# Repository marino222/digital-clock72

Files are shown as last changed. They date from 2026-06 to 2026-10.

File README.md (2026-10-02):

# Digital Kinetic Art Clock 

This project is the digital successor to my [ClockClock24 Project](https://github.com/marino222/clockclock24-replica), a replica of the kinetic art piece by [Humans Since 1982](https://www.humanssince1982.com/en-int). The original features physical clock hands driven by stepper motors, which brings challenges around power supply and makes scaling difficult.

This version replaces the clock hands with round LCD displays, which opens up new possibilities beyond just showing the time: animations, a snake game across all displays, or custom widgets. Since the digital version draws significantly less current and is expected to cost less overall, the target scale is a 12×6 display array rather than the 8×3 clocks of the predecessor.

> **Status:** A work in progress

---

## Table of contents

- [Vision](#vision)
- [Key decisions](#key-decisions)
- [How it works](#how-it-works)
- [Repository layout & component status](#repository-layout--component-status)
- [Roadmap](#roadmap)
- [Open questions](#open-questions)

---

## 🌅 Vision

My goal is to build a wall mounted array of round LCD displays that act together as one big synchronized screen. Each display sits in its own spot in a grid, similar to the clocks in the predecessor, but instead of physical hands every spot now has its own small screen.

At first, the array will simply show the time. But since every spot is now a real screen and not just a pair of clock hands, I plan to add more features over time. This includes smooth animations where the hands ease in and out instead of jumping, geometric patterns that move across the whole grid, a snake game that can be played across all displays at once, and small widgets like weather or notifications.

One central computer (likely a Raspberry Pi) will control the whole array and decide what should be shown. It sends this information to every display, and each display takes care of showing its own part of the picture.

---

## 🧩 Concept 

| Aspect | Choice | Why |
|---|---|---|
| Architecture | Master for calulation / Slave for rendering | Real time pixel drawing and global logic need different hardware |
| Master | Raspberry Pi 3, headless Linux broadcasts state at 60 Hz | Global logic and the web UI run better on a Pi than on a microcontroller |
| Node (Slave) | 1× bare RP2040 + 1× GC9A01 round LCD, on a small custom PCB | One identical board, JLCPCB assembled, just replicated |
| Bus | RS485, daisy chained node to node | Carries tiny state packets instead of full frames, so it scales cleanly |
| Applications | Time, animated patterns, array wide games (Snake) | All just different states broadcast by the master |

---

## ⚙️ How it works

To make the vision above work, the project splits the thinking and the drawing onto different controllers. One controller calculates the global image/animation and broadcasts these to the nodes. Each node controller then renders its individual pixels and displays them.

```
        ┌───────────────────────────────────────────────┐
        │  MASTER (Raspberry Pi 3)                      │
        │  • Headless Linux, C#                         │
        │  • Time sync, global vector math, game logic  │
        │  • Web UI for control/config                  │ 
        └───────────────────────┬───────────────────────┘
                                │  RS485 bus (broadcast)
                                │  tiny state packets @ 60 FPS
        ┌───────────┬───────────┼───────────┬───────────┐
        ▼           ▼           ▼           ▼           ▼
     ┌──────┐    ┌──────┐    ┌──────┐    ┌──────┐    ┌──────┐
     │ NODE │    │ NODE │    │ NODE │    │ NODE │    │ NODE │  
     │RP2040│    │  +   │    │  +   │    │  +   │    │  +   │
     │GC9A01│    │ LCD  │    │ LCD  │    │ LCD  │    │ LCD  │
     └──────┘    └──────┘    └──────┘    └──────┘    └──────┘
   Each node renders its own pixels locally from the shared global state.
```

### The master and the slave nodes

One computer, the master controller, runs the whole logic. It keeps track of time, decides what the array should be displaying, and runs a simple web page so it can be controlled. Every screen has its own slave controller, together they make up a node. Each node holds the picture for its own screen and draws it fast enough to keep up with all the others. It also knows its own position in the grid, so it only draws its own little piece of the bigger picture. The work is split this way because one controller can think for the whole array, but it cannot draw fast enough on dozens of screens by itself. And a tiny slave controller is fast enough to draw one screen, but it is too small to run all the planning logic. Splitting the work lets both sides do what they are good at. There is also a hard numeric reason the nodes have to render locally. One screen is 240×240 pixels at 16-bit color (RGB565), so one full frame is 240 × 240 × 2 bytes ≈ **112.5 KiB**. The RP2040 on each node has 264 KiB of SRAM, so it comfortably fits a double buffer for its *own* screen (≈225 KiB) with room to spare.

Read more about the master controller in [`master/README.md`](master/README.md), about the nodes in [`slave/README.md`](slave/README.md), and about the
hardware behind them in [`pcb/README.md`](pcb/README.md).

### How the data is sent to the nodes

Here is the idea that makes the whole array possible. The master does not send a full picture to every screen, sixty times a second. That would be far too much data. Instead, it sends a tiny instruction, something like "the hand should now point at 45 degrees" or "the snake is now at position 12, 2." Every node controller receives the exact same tiny instruction at the exact same moment, and draws its own piece of the picture from it. Streaming one full frame to one screen at 60 FPS is 112.5 KiB × 60 ≈ **6.6 MB/s**, for a single screen alone. For 9 nodes that is already ≈ 60 MB/s, at the full 72-node array it is ≈ 475 MB/s. A wired RS485 bus, the kind of connection this project uses, realistically carries somewhere in the low single-digit Mbit/s over a long daisy chain, several hundred times too little. A state instruction, on the other hand, is a handful of bytes sent once, at 60 Hz, no matter how many screens are listening. That gap is the entire reason the master only ever sends instructions, never pixels. This has three nice side effects. It needs very little data, since an instruction is just a handful of bytes instead of a full image. It keeps everything in sync automatically, since every screen hears the same instruction at the same time. And it scales easily, since adding more screens does not change how much data the brain has to send.

To reliably send state instruction a Data Protocol needs to be defined. Read more about this in [`master/README.md`](master/README.md) and [`slave/README.md`](slave/README.md).

### What actually will be displayed

This instruction can describe anything, which is what makes the project exciting. So far the plan includes:

- **Time:** the original purpose, digits and clock faces drawn across the grid.
- **Geometric and animated patterns:** motion across the whole grid, with easing animations instead of sudden jumps.
- **A snake game:** one game played across the entire array at once.
- **Small widgets:** controlled from the brain's simple web page.
- **Gifs**

---

## 📦 Repository layout & component status

```
Digital Clock 72/
├── 3D files/
│   ├── final/
│   └── test/
├── docs/
│   ├── datasheets/
│   └── images/
├── master/
│   └── README.md
├── slave/
│   └── README.md
├── pcb/
│   ├── node-pcb/
│   └── README.md
├── tests/
│   ├── phase-1.1-display-performance/
│   └── README.md
└── README.md
```

| Path | Tech | Role | Status |
|---|---|---|---|
| **master/** | C# on Pi 3 | Global logic, time sync, vector math, games, web UI, RS485 broadcast | Conceptual |
| **slave/** | C++ (PlatformIO), RP2040 | Framebuffer + SPI/DMA rendering, RS485 receive, local draw, auto-addressing | Conceptual |
| **node_pcb/** | KiCad | Single-node board (RP2040 + GC9A01 display header + RS485 + power + USB-C/SWD) | In design |
| **tests/** | — | Bring-up plan test procedures and recorded results, one folder per phase | Not started |

---

## 🗺️ Roadmap

This roadmap tracks the project progress. The approach is to test cheap, risky parts first before committing to PCB production. The prototype is a **3×3 (9-node)** array, large enough to validate the bus, addressing, and power distribution without high cost. Notes for each phase are listed in [`tests/`](tests/).

| Phase | Goal | Status |
|---|---|---|
| 1 | Test a single display at 60 FPS and measure power | ✅ Completed|
| 2 | Prove the RS485 link with a disposable test sender | ✅ Completed |
| 3 | Prove the state protocol and slave firmware on breadboards | ✅ Completed|
| 4 | Confirm the display hardware | ⚙ In progress |
| 5 | Build small prototype | ⚙ Not started |
| 6 | Scale to 24, then 72 nodes | ⬜ Not started |
| 7 | Add applications and the web UI | ⬜ Not started |

<details>
<summary><strong>1. Test a single display at 60 FPS and measure power</strong></summary>

**1.1 Display performance (breadboard)**
- One GC9A01 dev board driven by a Pico
- Aim for 60 FPS

**1.2 Power measurement (run during 1a)**
- Measure how much power a single display and Pico consume

</details>

<details>
<summary><strong>2. Prove the RS485 link with a disposable test sender</strong></summary>

A slave can't be tested without something transmitting packets, so a sender has to exist this early, but it doesn't need to be the real master. A minimal, throwaway sender (a second Pico, or even a PC-side script) is enough to put bytes on the bus.

**2.1 RS485 link (breadboard)**
- Two Picos + two cheap RS485 breakout modules (MAX3485 / THVD1450).
- One Pico runs a minimal, disposable packet sender the other renders them as a slave.
- The packet should contain very basic instructions so the slave can draw something

</details>

<details>
<summary><strong>3. Prove the state protocol and slave firmware on breadboards</strong></summary>

Develop and test the state protocol and rendering pipeline on breadboards before committing to custom PCBs. Use a Pico as a sender.

**3.1 Protocol design**
- Define and implement the state protocol: time display, basic drawing instructions, interface to implement widgets later
- Build the slave display-list executor: the firmware loop that parses commands, calls into a graphics library (TFT_eSPI or LovyanGFX) and displays pictures

**3.2 Physical testing**
- Test sync accross multiple nodes on 2–3 Picos: one sender, two slaves rendering the same broadcast
- Addressing here is manual, daisy-chain auto-addressing comes later

</details>

<details>
<summary><strong>4. Confirm the display hardware</strong></summary>

**4.1 Display hardware samples**
- Order a handful of the chosen GC9A01 breakout displays before finalizing any PCB.
- Confirm the breakout's pinout/pin order and its mounting-hole pattern / board outline, so the node board's mating board-to-board header position and any standoffs line up

</details>

<details>
<summary><strong>5. Build small prototype</strong></summary>

Before any further testing we should design the PCB as best as we can. Since the minimum order on JLCPCB is 5 pieces, 4 of them should be used to build a 2x2 prototype.

**5.1 PCB Prototype design**
- Design PCB
- Order a small batch (5 Pcs.) and bring up one board: power rails, USB enumeration, flashing, display, RS485 loopback.
- Test if the board works fine: Try to send data packets via RS485 using the sender from Phase 1b
- Measure the power consumption of this board

**5.2 2x2 prototype**
- Add daisy-chain auto-addressing in firmware, now that multiple nodes make it meaningful.
- Create a first version of the master controller in C#
- Assemble prototype and run tests
- Watch for voltage drops along the chain and try the mid-chain injection point to see how much it helps.

</details>

<details>
<summary><strong>6. Scale to 24, then 72 nodes</strong></summary>

**6.1 Scale**
- With real power numbers and a working board/bus, scale up.
- Power distribution will probably need its own pass at this size (multiple supplies, injection points, trace/connector currents).
- Adjust PCB design if anything arises

</details>

<details>
<summary><strong>7. Add applications and the web UI</strong></summary>

**7.1 Applications & web UI**
- Patterns, Snake, widgets. Once the transport feels solid, this part is mostly open-ended.

</details>

---

## ❓ Open questions

- **Power at scale.** See node_pcb's
- **Broadcast protocol definition.** Exact protocol definition. Needs to be implemented in `master` and `slave`.
- **Addressing scheme (firmware).** Daisy-chain auto-addressing to be *implemented* in firmware.
- **Syncing** How to make sure all displays run in sync

---

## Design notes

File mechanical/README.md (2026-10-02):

# Mechanical Design

The project needs an enclosure, plus parts to hold the node PCBs in place.

## Concept

The sketch below shows the rough concept of the clock's physical layout: a 12x6 grid of displays, aligned vertically. A software change could tilt this alignment instead.

The display's [technical drawing](/docs/datasheets/HZ0128QVPHGWS01N-AA.pdf) gives an outer diameter of ≈36 mm. Spacing the displays 44 mm apart gives a visually pleasing result.

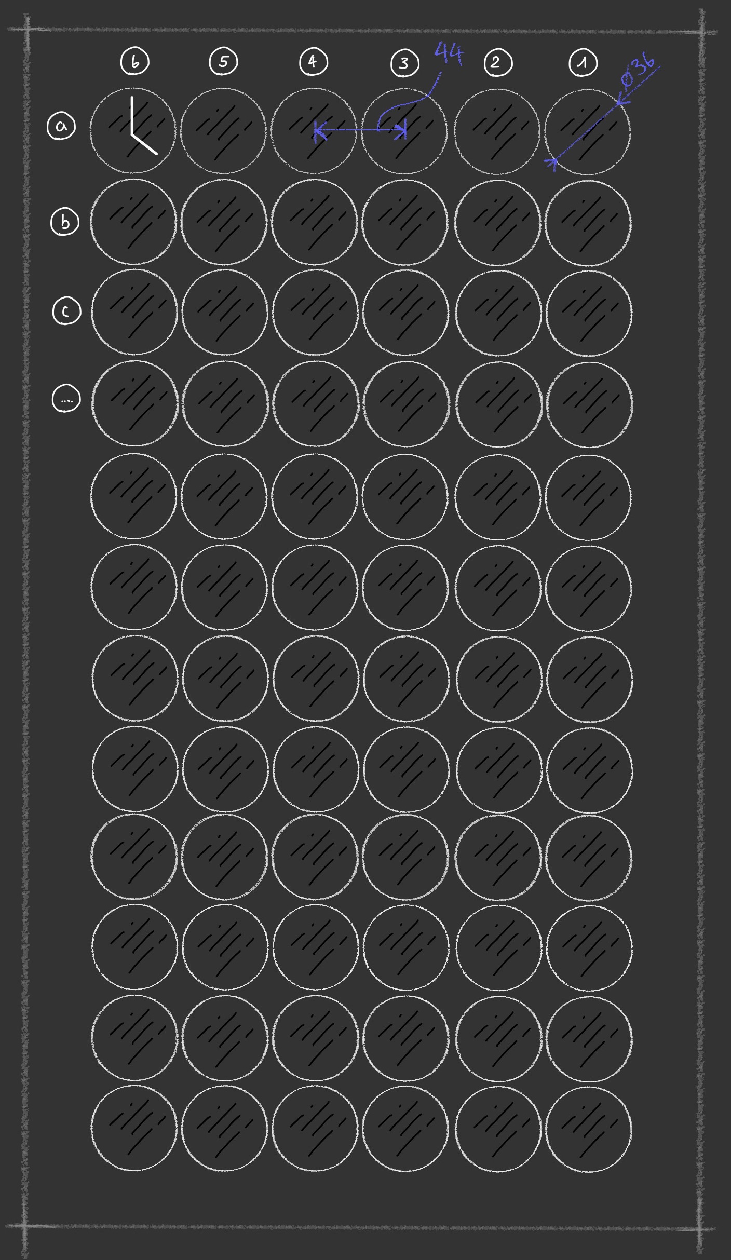
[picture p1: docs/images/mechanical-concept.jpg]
Concept sketch


This spacing means each PCB must fit within 44 x 44 mm, as shown below.

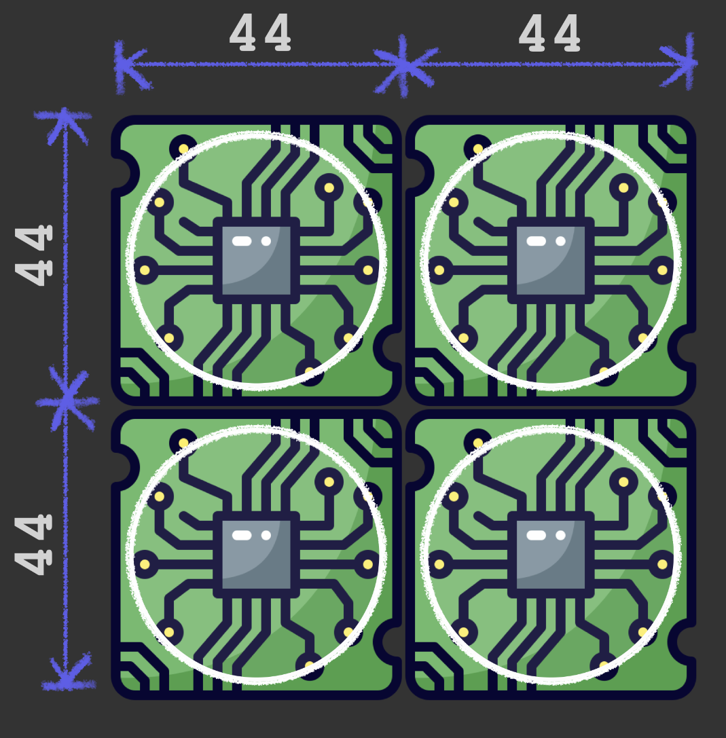
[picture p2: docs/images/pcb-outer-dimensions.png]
PCBs outer dimensions


### PCB outline

The sketch below shows how a node is assembled. The display panel is stuck onto the back of the PCB, and its FPC connector tail wraps around the PCB's edge to reach the connector. A small cutout is needed for the tail so it doesn't interfere with neighboring PCBs. The connector's position will need to match the actual tail length.

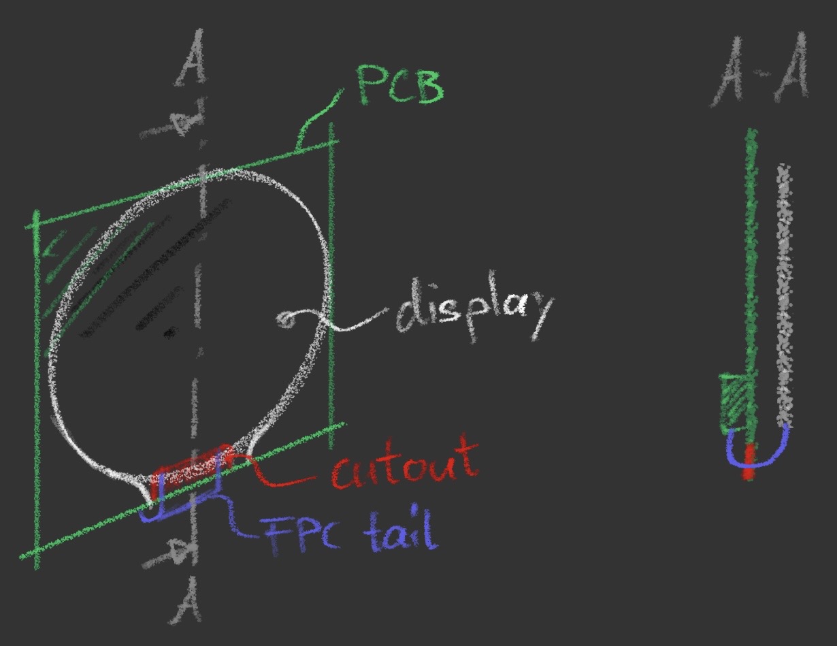
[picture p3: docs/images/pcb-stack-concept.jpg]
PCB stack concept


This gives us the PCB outline shown below, which we need to follow.

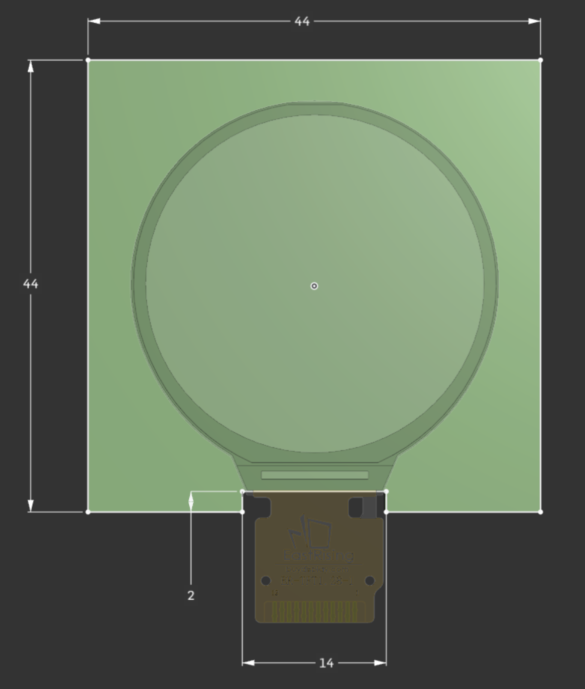
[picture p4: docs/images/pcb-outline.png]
PCB outline


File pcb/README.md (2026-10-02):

# Node PCB

Each pixel node is one self contained board carrying one microcontroller and one round LCD, wired to its neighbors over a shared bus. The full array is this same board built N times, with a target of 72 nodes. This README describes one of the nodes.

## What the board contains

- An RP2040 microcontroller and an external flash chip
- A connector for the GC9A01 round LCD
- An RS485 transceiver and two bus connectors so boards can be daisy chained
- Power regulation, with separate rails for the logic and the display backlight
- USB-C and/or SWD pads for flashing firmware

## Design reference

The board layout follows Raspberry Pi's RP2040 [hardware design guidelines](/docs/datasheets/hardware-design-with-rp2040.pdf), which include a minimal RP2040 example design. Its KiCad files are open source, so they are used as the starting reference.

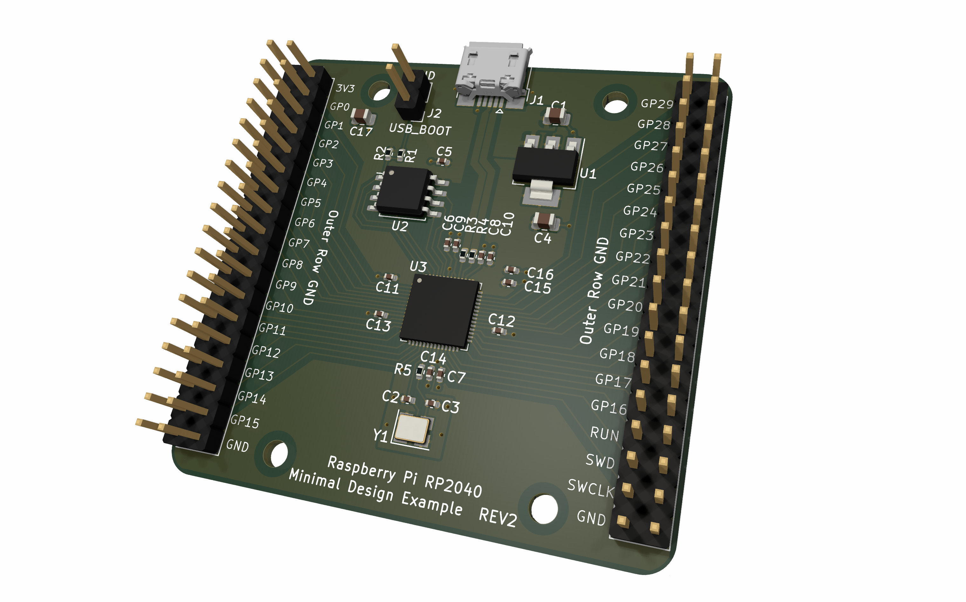
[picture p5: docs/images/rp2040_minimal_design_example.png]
RP2040 minimal design example


The image above shows this minimal design. Core components like the crystal oscillator, flash chip, and voltage regulator should stay the same. From there:

- Remove unnecessary I/O pins
- Add a 12-pin ZIF connector for the display
- Add the components needed for RS485 communication
- Add connectors for the power supply (power is not longer supplied via USB)
- Replace the Bootsel jumper pins (J2) with a button

Only SMD components are used, so the boards can be assembled by machine.

## Block diagram 

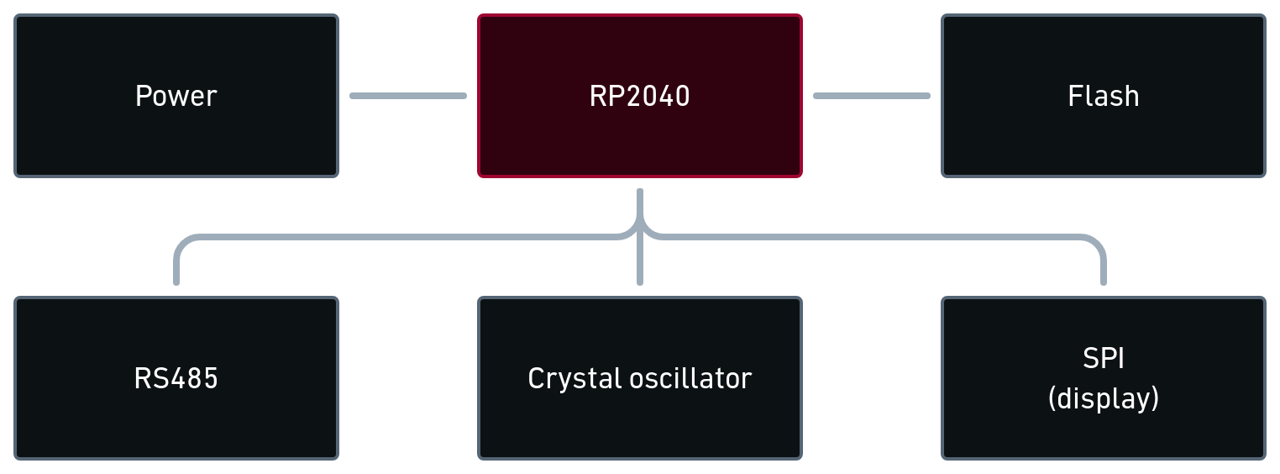
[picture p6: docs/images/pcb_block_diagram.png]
Block diagram of PCB components


## List of components

> All components need to be available in the JLCPCB parts library so they can be used for automatic assembly. Should they not be available, a suitable alternative has to be found.

Common parts like resistors and capacitors are not shown in this list. They may be viewed on the BOM of the final PCB design.

| Part | Manufacturer number | JLCPCB part number |  used in reference design |
| --- | --- | --- | --- |
| MCU | RP2040 | C2040 | ✅ |
| Flash, 4 MB | W25Q32JVS | C97521 | ✅ |
| Crystal, 12 MHz | ABM8-272-T3 | C20625731 | ✅ |
| USB-C connector | TYPE-C-31-M-12 | C165948 | ❌ |
| BOOTSEL button | TS-1187A-B-A-B | C318884 | ❌ |
| RS485 transceiver | THVD1450DR | C2671361  | ❌ |
| ZIF, vertical | AFC11-S12ICA-00 | C262499 | ❌ |
| Schottky diode | B5819W SL | C8598 | ❌ |
| JST connector, 8-pin | BM08B-GHS-TBT(LF)(SN) | C133062 | ❌ |
| LDO voltage regulator | AP2112K-3.3TRG1 | C51118 | ❌ |

> Note that the listed flash chip isn't the same as in the reference design. There a 16 Mb chip is used, which is very likely overkill for this project. To save costs this is scaled down to a 4 Mb chip. For this purpose the [hardware design guidelines](/docs/datasheets/hardware-design-with-rp2040.pdf) explicitly states that most 25-series flash devices may be used. So by using a smaller capacity storage from the same manufacturer shouldn't cause any trouble.

---
---
# Designing the PCB

As a starting point, the KiCad files of the minimal example mentioned above we're copied. 

## Adjusting schematic

The first step is to adjust the [schematic](/docs/datasheets/rp2040-design-example-schematic.pdf) to our needs.

### Power supply

<table>
    <tr>
        <td><b>Before</b></td>
        <td><b>After</b></td>
    <tr>
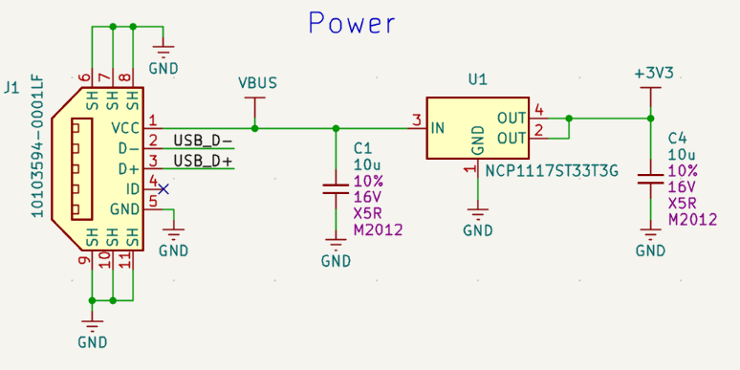
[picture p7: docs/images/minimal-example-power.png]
Minimal design example power block
        <td></td>
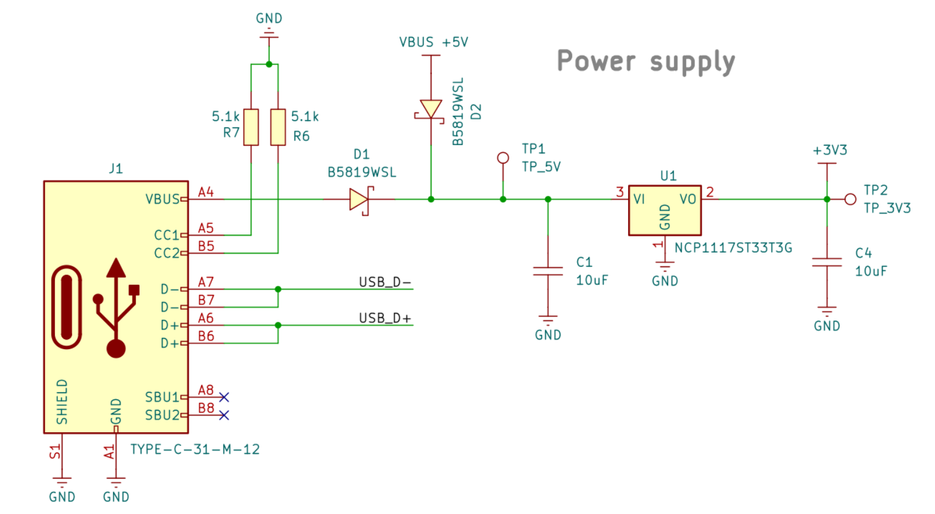
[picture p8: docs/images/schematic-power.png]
schematic power block
        <td></td>
    </tr>
</table>

The image on the left shows the power block of the minimal example, the image on the right shows our version. What changed:

- The Micro USB connector is replaced by a USB-C connector (J1). Its shield pins are tied directly to ground. The two D+ pins (A6/B6) are tied together, and so are the two D- pins (A7/B7), so the port works in either plug orientation. Both pairs then run to the MCU through 33 Ω series resistors.
- CC1 and CC2 are each pulled down with a 5.1 kΩ resistor. This is what tells the host that our board is a sink, so it enables +5 V on VBUS.
- To supply a steady 3.3V, the AP2112K-3.3TRG1 voltage regulater was chosen. This differs from the reference design, mainly because it has a lower dropout voltage (see below)

**Two power sources, two diodes**

During normal operation the board is not powered over USB, that port is only for development and testing. Power comes in over a JST connector, which also carries the RS485 signal lines. Each node has two of these connectors, so a board can be passed through to the next one in a daisy chain.

That means both sources can be present at the same time, so two Schottky diodes keep them apart:

- **D1** sits between the USB-C VBUS pin and the board's internal +5 V node. It lets the USB port feed the board, but blocks current from flowing back into the USB connector.
- **D2** sits between the bus (JST) +5 V net and that same internal node. It lets the bus feed the board, but stops the USB port from feeding the other boards on the bus.

If both sources are active, the board is simply supplied from the one with the higher potential. The price for this protection is a voltage drop across the diode, which is what the rest of this section is about.

#### How much input voltage does one board need?

Figure 1 shows a simplified version of our power supply circuit. The standard case is that the board is supplied from the VBUS line, so the path is JST → D2 → LDO.

<table>
    <tr>
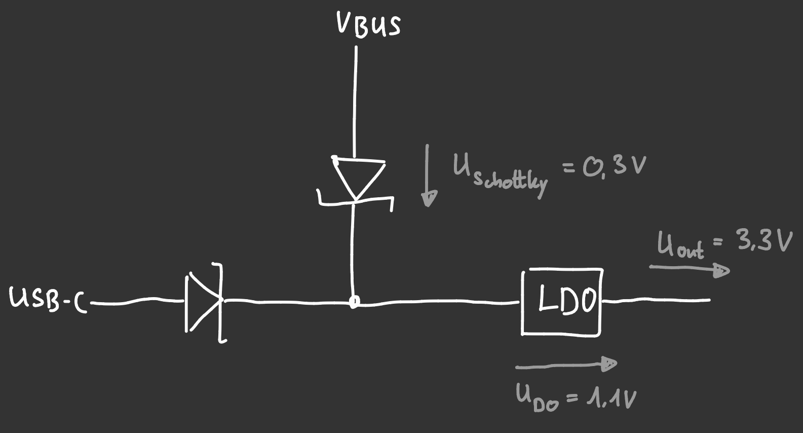
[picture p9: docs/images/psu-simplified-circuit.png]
Simplified power path of one node: VBUS and USB-C each feed the LDO through their own Schottky diode
        <td></td>
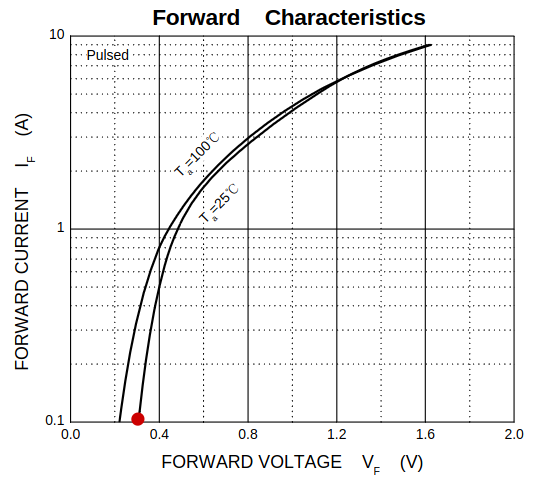
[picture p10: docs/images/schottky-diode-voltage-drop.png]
Forward current over forward voltage of the B5819W Schottky diode
        <td></td>
    </tr>
    <tr>
        <td><b>Figure 1:</b> Simplified power path of one node. Both inputs reach the LDO through their own Schottky diode, so whichever drives the input, one diode drop is always in the way.</td>
        <td><b>Figure 2:</b> Forward characteristics of the B5819W. At I_F = 100 mA (red dot) the forward voltage is roughly 0.3 V.</td>
    </tr>
</table>

In our [tests](/tests/README.md), a single Raspberry Pi Pico plus a display and RS485 module drew around 60 mA. We round this up generously to **100 mA per board**.

Two parts in that path define the minimum input voltage, both taken at 100 mA:

| Part | Value at 100 mA | Source |
| --- | --- | --- |
| Schottky diode (B5819W) | V_F ≈ 0.3 V | [datasheet](/docs/datasheets/schottky-diode-B5817W-589W.pdf), see Figure 2 |
| AP2112K LDO | V_in - V_out ≈ 45 mV | [datasheet](/docs/datasheets/AP2112-LDO.pdf), see Performance Characteristics |

The 45 mV is the LDO's *dropout voltage*: the **minimum** difference the regulator needs between its input and its output. If V_in - V_out falls below it, the LDO drops out of regulation and the 3.3 V rail starts to sag. With V_out = 3.3 V that gives:

```
V_in(LDO) >= V_out + V_dropout = 3.3 V + 0.045 V = 3.345 V
V_bus     >= V_in(LDO) + V_F   = 3.345 V + 0.3 V = 3.645 V
```

So the +5 V on the bus connector must never drop below **≈3.7 V**, anywhere in the installation.

#### How much is left at the last board?

Since we're not living in an ideal world, the supply voltage won't be exactly 5.0 V. We assume the boards are arranged in 12 rows of 6, with a power injection point at the start of each row, as shown in the diagram below. Each row then draws around 6 × 100 mA = 600 mA, which the JST connectors handle comfortably (the GH series is rated for 1.0 A). Most power supply manufacturers specify a voltage tolerance of ±5 %, so in the worst case the PSU delivers 4.75 V instead of 5.00 V.

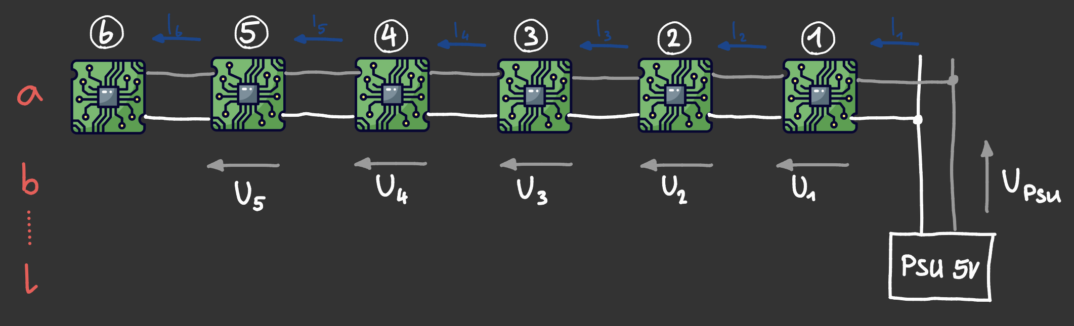
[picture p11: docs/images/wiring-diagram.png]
Wiring diagram


The worst case is node a6: it is the last board of a row and therefore the furthest away from the PSU. Between it and the injection point sit 5 boards and the wires between them, and each of them adds resistance (contacts, pcb traces, wires).

**Estimated resistance per board**

The [datasheet](/docs/datasheets/BM08B-GHS-TBT(LF)(SN).pdf) specifies a contact resistance of 30 mΩ.

Together with the PCB traces and the wire to the next board, we estimate roughly **100 mΩ per hop** for the whole current loop (supply and ground return). The table below shows the resulting voltage drops, with U_n and I_n as labelled in the diagram above:

| Hop | Current | Voltage drop (U = R × I) |
| --- | --- | --- |
| U1 | I1 = 600 mA | 60 mV |
| U2 | I2 = 500 mA | 50 mV |
| U3 | I3 = 400 mA | 40 mV |
| U4 | I4 = 300 mA | 30 mV |
| U5 | I5 = 200 mA | 20 mV |
| **Total** | | **200 mV** |

```
4.75 V (PSU worst case) - 0.20 V (wiring) = 4.55 V at node a6
```

That is well above the minimum of **3.7 V** we calculated earlier.

### Flash storage

<table>
    <tr>
        <td><b>Before</b></td>
        <td><b>After</b></td>
    </tr>
    <tr>
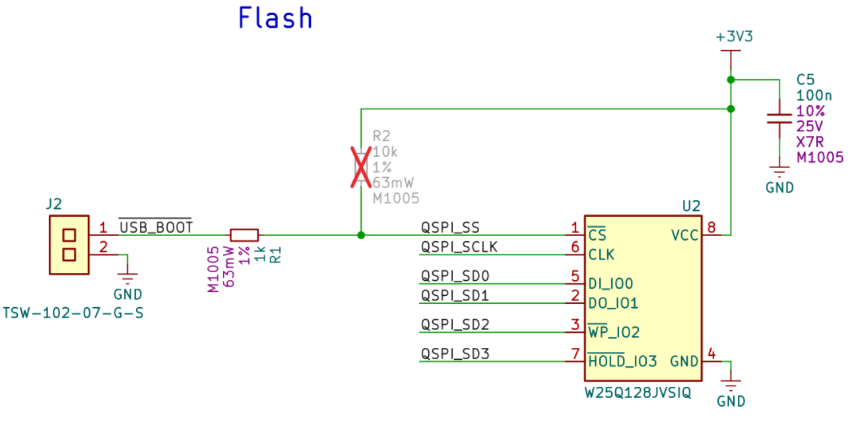
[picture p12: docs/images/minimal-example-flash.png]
Minimal design example flash block
        <td></td>
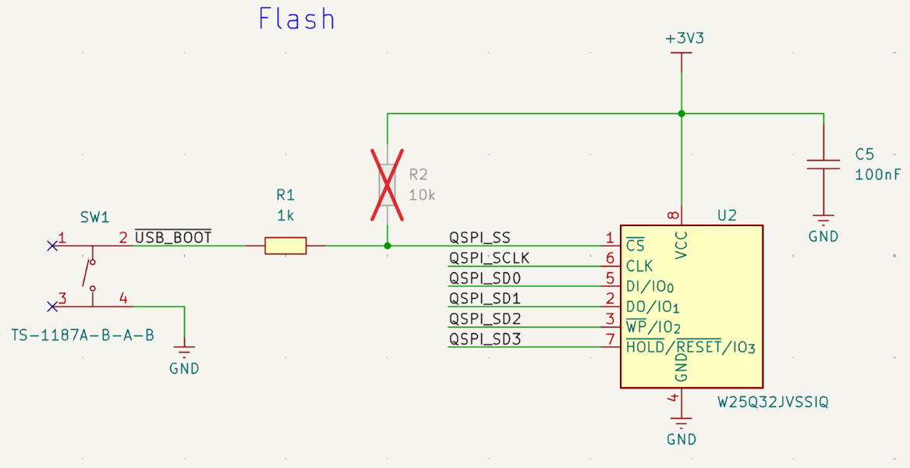
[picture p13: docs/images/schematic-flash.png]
schematic flash block
        <td></td>
    </tr>
</table>

The only changes here are replacing the BOOTSEL jumper J2 with a button (SW1) for easier entry into bootselect mode, and swapping in a different flash chip that shares the exact same footprint as the one in the reference design.

### RS485 communication

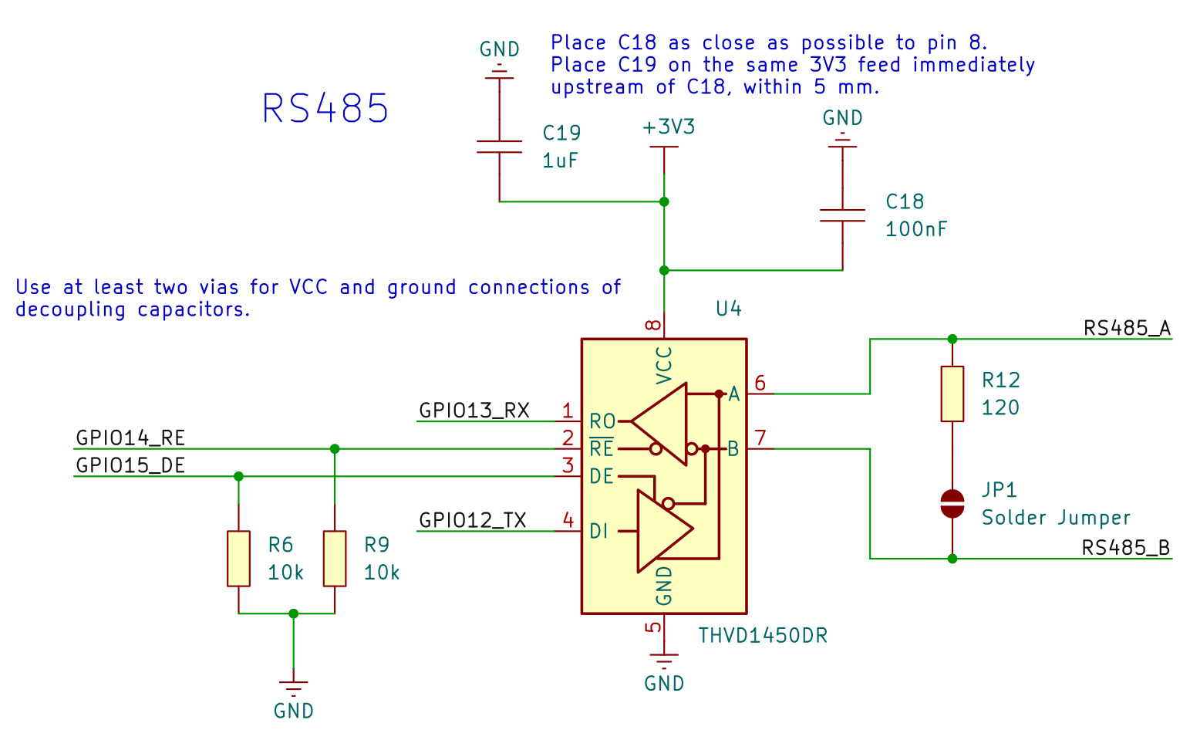
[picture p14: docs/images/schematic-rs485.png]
Schematic RS485


**Why this transceiver.** The THVD1450DR is a 1/8 unit-load part, so up to 256 nodes can share one bus segment. Since the array targets 72 nodes, that leaves plenty of headroom. It is also a common, widely available part and is stocked by JLCPCB.

**What the circuit does.** U4 runs off +3V3 and connects the RP2040's UART to the differential pair:

- `GPIO12_TX` → `DI` and `RO` → `GPIO13_RX` carry the data.
- `GPIO15_DE` and `GPIO14_RE` control the direction. Both are pulled to GND through 10 kΩ (R6, R9), so on power-up the driver is disabled and the receiver is enabled.
- C18 (100 nF) sits directly at pin 8, with C19 (1 µF) immediately upstream on the same 3V3 feed.

This follows the layout guidelines in the chip's [datasheet](/docs/datasheets/thvd1450.pdf), which ask for a 100–220 nF cap as close as possible to VCC, at least two vias per decoupling connection, and 1–10 kΩ resistors on the enable lines to limit noise currents during transients. 

**Termination.** R12 (120 Ω) is populated on every board but sits in series with solder jumper JP1, so it is only in circuit once that jumper is bridged. That matters because of how the array is wired. Looking back at the [wiring diagram](/docs/images/wiring-diagram.png), this is not one continuous bus. The 72 nodes are split into 12 rows of 6, each fed from its own injection point, so electrically there are 12 separate branches. Each branch is a short run, and terminating all 24 ends is likely overkill. How many jumpers actually need bridging still has to be measured on real hardware.

### Daisy chain connector

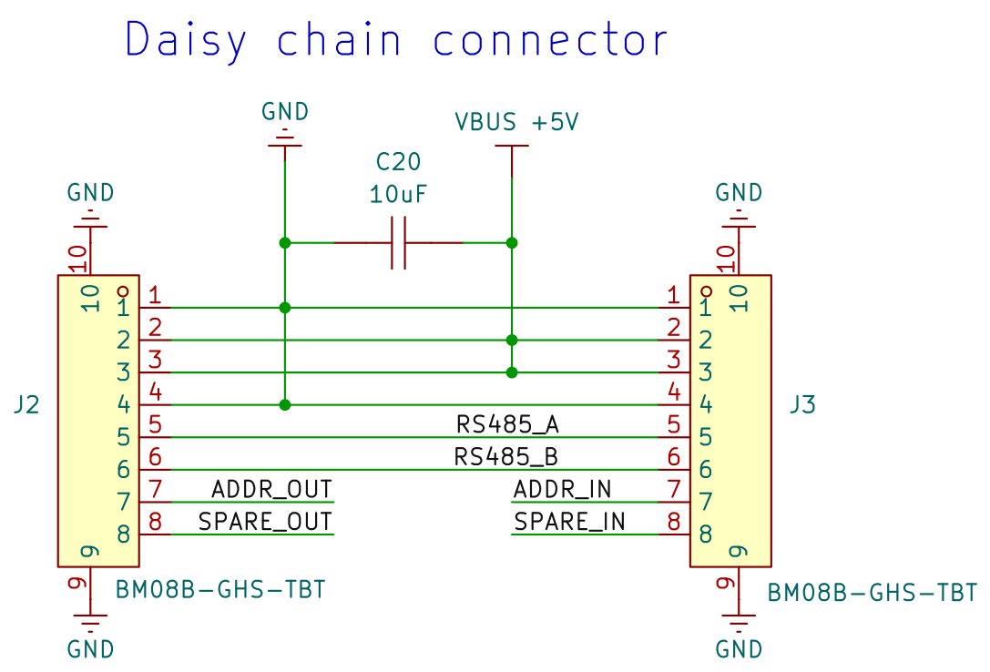
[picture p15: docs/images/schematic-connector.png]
Schematic daisy chain connector


Boards are linked with 8-pin JST GH connectors (BM08B-GHS-TBT), one in (J3) and one out (J2). 

The eight lines are allocated as follows:

| Pins | Net | Notes |
| --- | --- | --- |
| 1, 4 | GND | Split across two pins |
| 2, 3 | +5V (VBUS) | Split across two pins |
| 5, 6 | RS485_A / RS485_B | Passed straight through |
| 7 | ADDR | Point to point, for auto-addressing |
| 8 | SPARE | Point to point, reserved |

Power and ground each get two pins on purpose. The GH series is rated for 1.0 A per contact with AWG #26 wire, so doubling up gives a comfortable 2 A budget.

The last two lines are wired differently from the rest. Power, ground and the RS485 pair passed straight through the board, `ADDR` and `SPARE` are not. `ADDR_IN`/`SPARE_IN` on J3 and `ADDR_OUT`/`SPARE_OUT` on J2 are four separate nets going to four separate GPIOs. `ADDR` is used for the auto adressing feature. `SPARE` is the same arrangement with nothing assigned to it yet, wired up proactively so a future feature can use it without a board change.

C20 (10 µF) provides local bulk decoupling between +5V and GND at the connector.
AP2112K-3.3TRG1

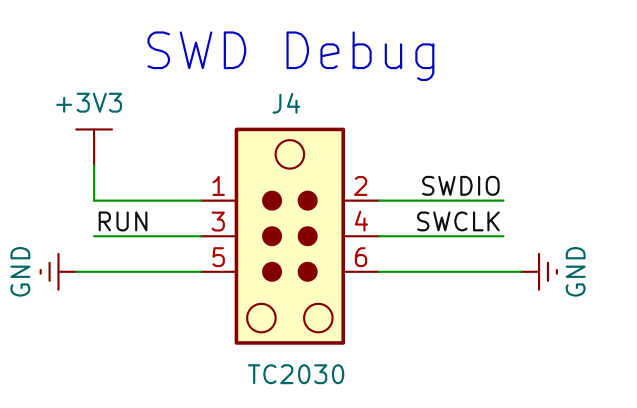
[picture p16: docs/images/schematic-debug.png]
Schematic SWD debug


An SWD header (J4) was added alongside USB-C to make flashing and debugging easier. The footprint is a standard TC2030, which needs no connector on the board at all. A pogo pin cable is simply pressed against the pads.

On the other end, the plan is to drive it from a second Raspberry Pi Pico running the official debugprobe firmware, which handles both flashing and interactive debugging over the same three wires.

### SPI display

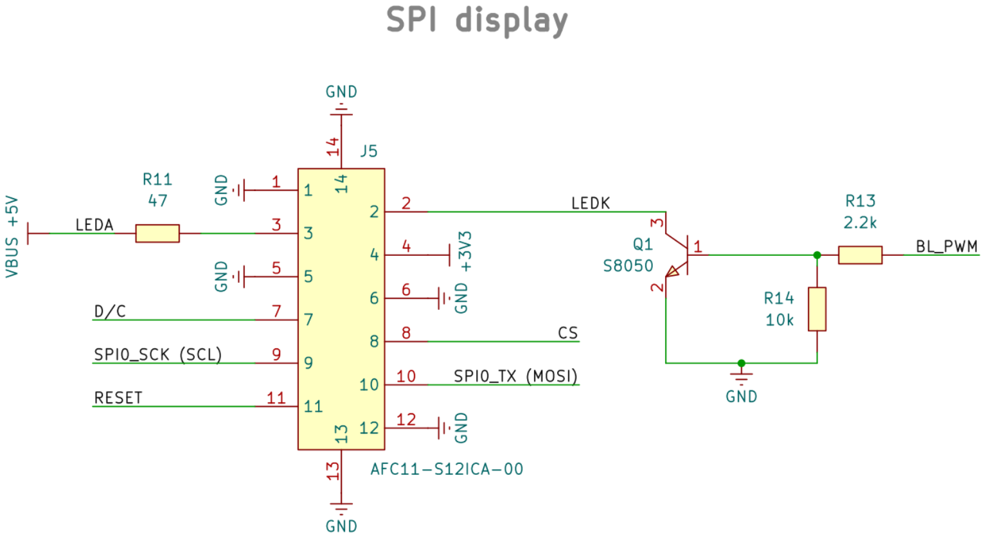
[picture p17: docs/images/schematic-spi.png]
Schematic SPI


The display's FPC tail plugs into J5, a 12-pin ZIF (zero insertion force) connector, so the panel can be swapped without soldering. The assignment follows the tail pinout given in the panel [datasheet](/docs/datasheets/HZ0128QVPHGWS01N-AA).

| Pin | Net | Purpose |
| --- | --- | --- |
| 1 | GND | |
| 2 | LEDK | Backlight cathode, switched by Q1 |
| 3 | LEDA | Backlight anode, +5V through R11 |
| 4 | +3V3 | VDD, analog supply |
| 5, 6 | GND | |
| 7 | D/C | Data / command select |
| 8 | CS | Chip select, active low |
| 9 | SPI0_SCK | Serial clock |
| 10 | SPI0_TX | Serial data in |
| 11 | RESET | Active low |
| 12 | GND | |
| 13, 14 | GND | Mounting tabs |

Ten of the twelve pins are unremarkable: the 4-wire SPI signals, `RESET`, the 3V3 analog supply and four grounds. Note that VDD is specified as 2.8 V typical with an absolute maximum of 4.6 V, so it belongs on the logic rail, the +5V rail is only for the backlight.

**The backlight.** This is the one block that needs more than a wire. The panel carries two white LEDs in parallel, specified at VF ≈ 3.0 V and IF = 40 mA, and it has no driver of its own.

`LEDA` (pin 3) is fed from +5V rather than the 3V3 rail, because 3.3 V leaves almost no headroom above the 3.0 V forward voltage. `LEDK` (pin 2) is then switched low-side by Q1, an S8050 NPN. `BL_PWM` drives the base through R13 (2.2 kΩ), and R14 (10 kΩ) pulls the base down so the backlight stays dark until the firmware deliberately drives the pin. Varying the PWM duty cycle dims the display.

R11 (47 Ω) sits in series with the anode and sets the current:

```
I = (5 V − 3.0 V − 0.2 V) / 47 Ω ≈ 38 mA
```

with the 0.2 V accounting for Q1's collector-emitter saturation voltage. That lands just under the 40 mA rating, which is where we want to be.

## Open uncertainties

- The GC9A01 FPC tail spec (pin count, pitch, orientation) needs to be confirmed from physical samples, and the ZIF pin assignment corrected to match (see the SPI section).
- Real per node power draw (idle, full white, inrush) hasn't been measured yet.
- The THVD1450 is in the schematic, but the slower, lower-EMI THVD1410 may be the better fit for this bus.
- How many of the 12 branches actually need their 120 Ω termination jumper bridged has to be measured.
- Baud rate vs. max bus length for the largest planned install needs to be decided.

See the root [README.md](../README.md) for full system context.

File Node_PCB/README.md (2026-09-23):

# Node PCB

Each pixel node is one self contained board carrying one microcontroller and one round LCD, wired to its neighbors over a shared bus. The full array is this same board built N times, with a target of 72 nodes. This README describes one of the nodes.

## What the board contains

- An RP2040 microcontroller and an external flash chip
- A connector for the GC9A01 round LCD
- An RS485 transceiver and two bus connectors so boards can be daisy chained
- Power regulation, with separate rails for the logic and the display backlight
- USB-C and/or SWD pads for flashing firmware

## Design reference

The board layout follows Raspberry Pi's RP2040 [hardware design guidelines](/docs/datasheets/hardware-design-with-rp2040.pdf), which include a minimal RP2040 example design. Its KiCad files are open source, so they are used as the starting reference.

RP2040 minimal design example

The image above shows this minimal design. Core components like the crystal oscillator, flash chip, and voltage regulator should stay the same. From there:

- Remove unnecessary I/O pins
- Add a 12-pin ZIF connector for the display
- Add the components needed for RS485 communication
- Add connectors for the power supply (power is not longer supplied via USB)
- Replace the Bootsel jumper pins (J2) with a button

Only SMD components are used, so the boards can be assembled by machine.

## Block diagram 

Block diagram of PCB components

## List of components

> All components need to be available in the JLCPCB parts library so they can be used for automatic assembly. Should they not be available, a suitable alternative has to be found.

Common parts like resistors and capacitors are not shown in this list. They may be viewed on the BOM of the final PCB design.

| Part | Manufacturer number | JLCPCB part number |  used in reference design |
| --- | --- | --- | --- |
| MCU | RP2040 | C2040 | ✅ |
| Flash, 4 MB | W25Q32JVS | C97521 | ✅ |
| Crystal, 12 MHz | ABM8-272-T3 | C20625731 | ✅ |
| USB-C connector | TYPE-C-31-M-12 | C165948 | ❌ |
| BOOTSEL button | TS-1187A-B-A-B | C318884 | ❌ |
| RS485 transceiver | THVD1450DR | C2671361  | ❌ |
| ZIF, vertical | AFC11-S12ICA-00 | C262499 | ❌ |
| Schottky diode | B5819W SL | C8598 | ❌ |
| JST connector, 8-pin | BM08B-GHS-TBT(LF)(SN) | C133062 | ❌ |

> Note that the listed flash chip isn't the same as in the reference design. There a 16 Mb chip is used, which is very likely overkill for this project. To save costs this is scaled down to a 4 Mb chip. For this purpose the [hardware design guidelines](/docs/datasheets/hardware-design-with-rp2040.pdf) explicitly states that most 25-series flash devices may be used. So by using a smaller capacity storage from the same manufacturer shouldn't cause any trouble.

---
---
# Designing the PCB

As a starting point, the KiCad files of the minimal example mentioned above we're copied. 

## Adjusting schematic

The first step is to adjust the [schematic](/docs/datasheets/rp2040-design-example-schematic.pdf) to our needs.

### Power supply

<table>
    <tr>
        <td><b>Before</b></td>
        <td><b>After</b></td>
    <tr>
        <td>Minimal design example power block</td>
        <td>schematic power block</td>
    </tr>
</table>

The image on the left shows the power block of the minimal example, the image on the right shows our version. What changed:

- The Micro USB connector is replaced by a USB-C connector (J1). Its shield pins are tied directly to ground. The two D+ pins (A6/B6) are tied together, and so are the two D- pins (A7/B7), so the port works in either plug orientation. Both pairs then run to the MCU through 33 Ω series resistors.
- CC1 and CC2 are each pulled down with a 5.1 kΩ resistor. This is what tells the host that our board is a sink, so it enables +5 V on VBUS.
- The regulator stays as it is in the reference design: U1 (NCP1117) turns the +5 V input into the +3.3 V logic rail.

**Two power sources, two diodes**

During normal operation the board is not powered over USB — that port is only for development and testing. Power comes in over a JST connector, which also carries the RS485 signal lines. Each node has two of these connectors, so a board can be passed through to the next one in a daisy chain.

That means both sources can be present at the same time, so two Schottky diodes keep them apart:

- **D1** sits between the USB-C VBUS pin and the board's internal +5 V node. It lets the USB port feed the board, but blocks current from flowing back into the USB connector.
- **D2** sits between the bus (JST) +5 V net and that same internal node. It lets the bus feed the board, but stops the USB port from feeding the other boards on the bus.

If both sources are active, the board is simply supplied from the one with the higher potential. The price for this protection is a voltage drop across the diode, which is what the rest of this section is about.

#### How much input voltage does one board need?

Figure 1 shows a simplified version of our power supply circuit. The standard case is that the board is supplied from the VBUS line, so the path is JST → D2 → LDO.

<table>
    <tr>
        <td>Simplified power path of one node: VBUS and USB-C each feed the LDO through their own Schottky diode</td>
        <td>Forward current over forward voltage of the B5819W Schottky diode</td>
    </tr>
    <tr>
        <td><b>Figure 1:</b> Simplified power path of one node. Both inputs reach the LDO through their own Schottky diode, so whichever drives the input, one diode drop is always in the way.</td>
        <td><b>Figure 2:</b> Forward characteristics of the B5819W. At I_F = 100 mA (red dot) the forward voltage is roughly 0.3 V.</td>
    </tr>
</table>

In our [tests](/tests/README.md), a single Raspberry Pi Pico plus a display and RS485 module drew around 60 mA. We round this up generously to **100 mA per board**.

Two parts in that path define the minimum input voltage, both taken at 100 mA:

| Part | Value at 100 mA | Source |
| --- | --- | --- |
| Schottky diode (B5819W) | V_F ≈ 0.3 V | [datasheet](/docs/datasheets/schottky-diode-B5817W-589W.pdf), see Figure 2 |
| NCP1117 LDO | V_in - V_out = 1.10 V (max) | [datasheet](/docs/datasheets/NCP1117-LDO.PDF), 0.95 V typical / 1.10 V max |

The 1.10 V is the LDO's *dropout voltage*: the **minimum** difference the regulator needs between its input and its output. If V_in - V_out falls below it, the LDO drops out of regulation and the 3.3 V rail starts to sag. With V_out = 3.3 V that gives:

```
V_in(LDO) >= V_out + V_dropout = 3.3 V + 1.10 V = 4.40 V
V_bus     >= V_in(LDO) + V_F   = 4.40 V + 0.3 V = 4.70 V
```

So the +5 V on the bus connector must never drop below **4.7 V**, anywhere in the installation.

#### How much is left at the last board?

Since we're not living in an ideal world, the supply voltage won't be exactly 5.0 V. We assume the boards are arranged in 12 rows of 6, with a power injection point at the start of each row, as shown in the diagram below. Each row then draws around 6 × 100 mA = 600 mA, which the JST connectors handle comfortably (the GH series is rated for 1.0 A). Most power supply manufacturers specify a voltage tolerance of ±5 %, so in the worst case the PSU delivers 4.75 V instead of 5.00 V.

Wiring diagram

The worst case is node a6: it is the last board of a row and therefore the furthest away from the PSU. Between it and the injection point sit 5 boards and the wires between them, and each of them adds resistance (contacts, pcb traces, wires).

**Estimated resistance per board**

The [datasheet](/docs/datasheets/BM08B-GHS-TBT(LF)(SN).pdf) specifies a contact resistance of 30 mΩ.

Together with the PCB traces and the wire to the next board, we estimate roughly **100 mΩ per hop** for the whole current loop (supply and ground return). The table below shows the resulting voltage drops, with U_n and I_n as labelled in the diagram above:

| Hop | Current | Voltage drop (U = R × I) |
| --- | --- | --- |
| U1 | I1 = 600 mA | 60 mV |
| U2 | I2 = 500 mA | 50 mV |
| U3 | I3 = 400 mA | 40 mV |
| U4 | I4 = 300 mA | 30 mV |
| U5 | I5 = 200 mA | 20 mV |
| **Total** | | **200 mV** |

```
4.75 V (PSU worst case) - 0.20 V (wiring) = 4.55 V at node a6
```

That is 0.15 V short of the 4.7 V we calculated as the minimum input voltage.

In reality this will probably still be fine, because every assumption above is a worst case. The PSU at the bottom of its tolerance, 100 mA per board when we measured 60 mA, and the full current charged to every hop. On the other hand, the 0.3 V diode drop is read off a typical curve and not a guaranteed maximum, so it could also turn out slightly worse.

Either way, the 100 mΩ per hop is an estimate. Once the first batch of PCBs arrives we have to measure the actual resistance and the voltage that really arrives at the last node (see [tests](../tests/README.md#pcb-prototype-design) for the measured results).

### Flash storage

<table>
    <tr>
        <td><b>Before</b></td>
        <td><b>After</b></td>
    </tr>
    <tr>
        <td>Minimal design example flash block</td>
        <td>schematic flash block</td>
    </tr>
</table>

The only changes here are replacing the BOOTSEL jumper J2 with a button (SW1) for easier entry into bootselect mode, and swapping in a different flash chip that shares the exact same footprint as the one in the reference design.

### RS485 communication

Schematic RS485

**Why this transceiver.** The THVD1450DR is a 1/8 unit-load part, so up to 256 nodes can share one bus segment. Since the array targets 72 nodes, that leaves plenty of headroom. It is also a common, widely available part and is stocked by JLCPCB.

**What the circuit does.** U4 runs off +3V3 and connects the RP2040's UART to the differential pair:

- `GPIO12_TX` → `DI` and `RO` → `GPIO13_RX` carry the data.
- `GPIO15_DE` and `GPIO14_RE` control the direction. Both are pulled to GND through 10 kΩ (R6, R9), so on power-up the driver is disabled and the receiver is enabled.
- C18 (100 nF) sits directly at pin 8, with C19 (1 µF) immediately upstream on the same 3V3 feed.

This follows the layout guidelines in the chip's [datasheet](/docs/datasheets/thvd1450.pdf), which ask for a 100–220 nF cap as close as possible to VCC, at least two vias per decoupling connection, and 1–10 kΩ resistors on the enable lines to limit noise currents during transients. 

**Termination.** R12 (120 Ω) is populated on every board but sits in series with solder jumper JP1, so it is only in circuit once that jumper is bridged. That matters because of how the array is wired. Looking back at the [wiring diagram](/docs/images/wiring-diagram.png), this is not one continuous bus. The 72 nodes are split into 12 rows of 6, each fed from its own injection point, so electrically there are 12 separate branches. Each branch is a short run, and terminating all 24 ends is likely overkill. How many jumpers actually need bridging still has to be measured on real hardware.

> **Note on the part number.** The THVD1450 is the 50 Mbps variant of the family, the pin-compatible THVD1410 is the 500 kbps.

### Daisy chain connector

Schematic daisy chain connector

Boards are linked with 8-pin JST GH connectors (BM08B-GHS-TBT), one in (J3) and one out (J2). Two things made this the pick:

- **Top entry.** The gap between adjacent boards is not confirmed yet. A vertical connector routes the cable away from the board edge, so the gap size does not constrain the choice. A side-entry part (SM08B-GHS-TB) would.
- **SMT.** The whole board is machine assembled, and this header is surface mount, so no hand soldering step is needed.

The eight lines are allocated as follows:

| Pins | Net | Notes |
| --- | --- | --- |
| 1, 4 | GND | Split across two pins |
| 2, 3 | +5V (VBUS) | Split across two pins |
| 5, 6 | RS485_A / RS485_B | Passed straight through |
| 7 | ADDR | Point to point, for auto-addressing |
| 8 | SPARE | Point to point, reserved |

Power and ground each get two pins on purpose. The GH series is rated for 1.0 A per contact with AWG #26 wire, so doubling up gives a comfortable 2 A budget.

The last two lines are wired differently from the rest. Power, ground and the RS485 pair passed straight through the board, `ADDR` and `SPARE` are not. `ADDR_IN`/`SPARE_IN` on J3 and `ADDR_OUT`/`SPARE_OUT` on J2 are four separate nets going to four separate GPIOs. `ADDR` is used for the auto adressing feature. `SPARE` is the same arrangement with nothing assigned to it yet, wired up proactively so a future feature can use it without a board change.

C20 (10 µF) provides local bulk decoupling between +5V and GND at the connector.

### SWD debug interface

Schematic SWD debug

An SWD header (J4) was added alongside USB-C to make flashing and debugging easier. The footprint is a standard TC2030, which needs no connector on the board at all. A pogo pin cable is simply pressed against the pads.

On the other end, the plan is to drive it from a second Raspberry Pi Pico running the official debugprobe firmware, which handles both flashing and interactive debugging over the same three wires.

### SPI display

Schematic SPI

The display's FPC tail plugs into J5, a 12-pin ZIF (zero insertion force) connector, so the panel can be swapped without soldering. The assignment follows the tail pinout given in the panel [datasheet](/docs/datasheets/HZ0128QVPHGWS01N-AA.pdf), which the two [GoldenMorning T128HC](/docs/datasheets/display-datasheets/) drawings of the same 12-pin tail agree with:

| Pin | Net | Purpose |
| --- | --- | --- |
| 1 | GND | |
| 2 | LEDK | Backlight cathode, switched by Q1 |
| 3 | LEDA | Backlight anode, +5V through R11 |
| 4 | +3V3 | VDD, analog supply |
| 5, 6 | GND | |
| 7 | D/C | Data / command select |
| 8 | CS | Chip select, active low |
| 9 | SPI0_SCK | Serial clock |
| 10 | SPI0_TX | Serial data in |
| 11 | RESET | Active low |
| 12 | GND | |
| 13, 14 | GND | Mounting tabs |

Ten of the twelve pins are unremarkable: the 4-wire SPI signals, `RESET`, the 3V3 analog supply and four grounds. Note that VDD is specified as 2.8 V typical with an absolute maximum of 4.6 V, so it belongs on the logic rail, the +5V rail is only for the backlight.

**The backlight.** This is the one block that needs more than a wire. The panel carries two white LEDs in parallel, specified at VF ≈ 3.0 V and IF = 40 mA, and it has no driver of its own.

`LEDA` (pin 3) is fed from +5V rather than the 3V3 rail, because 3.3 V leaves almost no headroom above the 3.0 V forward voltage. `LEDK` (pin 2) is then switched low-side by Q1, an S8050 NPN: `BL_PWM` drives the base through R13 (2.2 kΩ), and R14 (10 kΩ) pulls the base down so the backlight stays dark until the firmware deliberately drives the pin. Varying the PWM duty cycle dims the display.

R11 (47 Ω) sits in series with the anode and sets the current:

```
I = (5 V − 3.0 V − 0.2 V) / 47 Ω ≈ 38 mA
```

with the 0.2 V accounting for Q1's collector-emitter saturation voltage. That lands just under the 40 mA rating, which is where we want to be.

## Open uncertainties

- The GC9A01 FPC tail spec (pin count, pitch, orientation) needs to be confirmed from physical samples, and the ZIF pin assignment corrected to match (see the SPI section).
- Real per node power draw (idle, full white, inrush) hasn't been measured yet.
- The THVD1450 is in the schematic, but the slower, lower-EMI THVD1410 may be the better fit for this bus.
- How many of the 12 branches actually need their 120 Ω termination jumper bridged has to be measured.
- Baud rate vs. max bus length for the largest planned install needs to be decided.

See the root [README.md](../README.md) for full system context.

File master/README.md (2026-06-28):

# Master_Engine

This will hold the brain of the array, the C# service that runs on a Raspberry Pi 3, keeps time, figures out what the array should be doing, and broadcasts that state to all the pixel nodes over RS485. It'll also host a small web UI for controlling and configuring the clock.

See the root [README.md](../README.md) for the full picture.

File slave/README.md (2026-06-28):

# Slave_Firmware

This will hold the firmware for a single pixel node, one RP2040 driving one round GC9A01 LCD. It needs to listen on RS485, decode whatever broadcast protocol the master controller sends, auto-address itself in the daisy chain, and render the clock face (and later patterns/Snake) at 60 FPS.

See the root [README.md](../README.md) for the full picture.

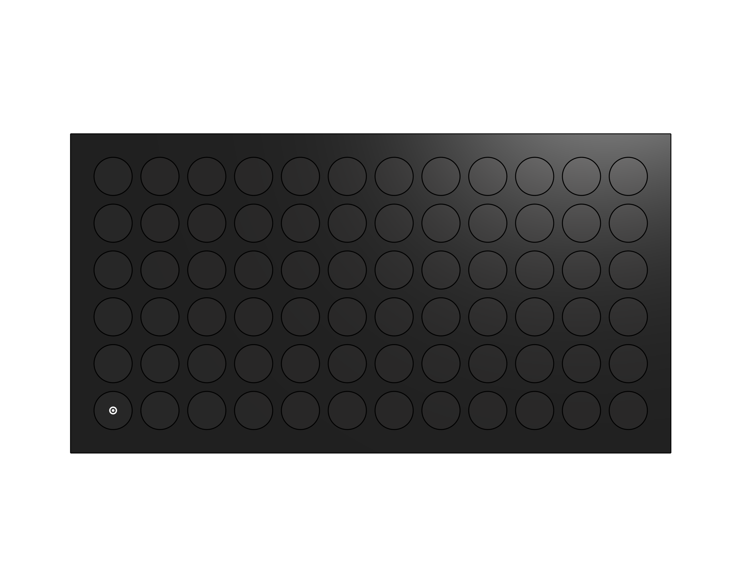
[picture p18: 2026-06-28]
docs/images/concept.png

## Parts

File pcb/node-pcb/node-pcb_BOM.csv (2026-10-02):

Reference | Description | Qty | LCSC Part | Value | Footprint | Datasheet | package | temp_coefficient | tolerance | voltage | Manufacturer
C1 | Ceramic Capacitor, SMD | 1 | C1525 | 100nF | JLCPCB:C0402 | https://lcsc.com/product-detail/Multilayer-Ceramic-Capacitors-MLCC-SMD-SMT_SAMSUNG_CL05B104KO5NNNC_100nF-104-10-16V_C1525.html | 0402 | X7R | ± 10% | 16V | Samsung Electro-Mechanics
C2 | Ceramic Capacitor, SMD | 1 | C1525 | 100nF | JLCPCB:C0402 | https://lcsc.com/product-detail/Multilayer-Ceramic-Capacitors-MLCC-SMD-SMT_SAMSUNG_CL05B104KO5NNNC_100nF-104-10-16V_C1525.html | 0402 | X7R | ± 10% | 16V | Samsung Electro-Mechanics
C3 | Ceramic Capacitor, SMD | 1 | C1525 | 100nF | JLCPCB:C0402 | https://lcsc.com/product-detail/Multilayer-Ceramic-Capacitors-MLCC-SMD-SMT_SAMSUNG_CL05B104KO5NNNC_100nF-104-10-16V_C1525.html | 0402 | X7R | ± 10% | 16V | Samsung Electro-Mechanics
C4 | Ceramic Capacitor, SMD | 1 | C1525 | 100nF | JLCPCB:C0402 | https://lcsc.com/product-detail/Multilayer-Ceramic-Capacitors-MLCC-SMD-SMT_SAMSUNG_CL05B104KO5NNNC_100nF-104-10-16V_C1525.html | 0402 | X7R | ± 10% | 16V | Samsung Electro-Mechanics
C5 | Ceramic Capacitor, SMD | 1 | C1525 | 100nF | JLCPCB:C0402 | https://lcsc.com/product-detail/Multilayer-Ceramic-Capacitors-MLCC-SMD-SMT_SAMSUNG_CL05B104KO5NNNC_100nF-104-10-16V_C1525.html | 0402 | X7R | ± 10% | 16V | Samsung Electro-Mechanics
C6 | Ceramic Capacitor, SMD | 1 | C1525 | 100nF | JLCPCB:C0402 | https://lcsc.com/product-detail/Multilayer-Ceramic-Capacitors-MLCC-SMD-SMT_SAMSUNG_CL05B104KO5NNNC_100nF-104-10-16V_C1525.html | 0402 | X7R | ± 10% | 16V | Samsung Electro-Mechanics
C7 | Ceramic Capacitor, SMD | 1 | C1525 | 100nF | JLCPCB:C0402 | https://lcsc.com/product-detail/Multilayer-Ceramic-Capacitors-MLCC-SMD-SMT_SAMSUNG_CL05B104KO5NNNC_100nF-104-10-16V_C1525.html | 0402 | X7R | ± 10% | 16V | Samsung Electro-Mechanics
C8 | Ceramic Capacitor, SMD | 1 | C1525 | 100nF | JLCPCB:C0402 | https://lcsc.com/product-detail/Multilayer-Ceramic-Capacitors-MLCC-SMD-SMT_SAMSUNG_CL05B104KO5NNNC_100nF-104-10-16V_C1525.html | 0402 | X7R | ± 10% | 16V | Samsung Electro-Mechanics
C9 | Ceramic Capacitor, SMD | 1 | C1525 | 100nF | JLCPCB:C0402 | https://lcsc.com/product-detail/Multilayer-Ceramic-Capacitors-MLCC-SMD-SMT_SAMSUNG_CL05B104KO5NNNC_100nF-104-10-16V_C1525.html | 0402 | X7R | ± 10% | 16V | Samsung Electro-Mechanics
C10 | Ceramic Capacitor, SMD | 1 | C77075 | 10uF | JLCPCB:C0805 | https://lcsc.com/product-detail/Multilayer-Ceramic-Capacitors-MLCC-SMD-SMT_muRata_GRM21BR61C106KE15L_10uF-106-10-16V_C77075.html | 0805 | X5R | ± 10% | 16V | Murata Electronics
C11 | Ceramic Capacitor, SMD | 1 | C77075 | 10uF | JLCPCB:C0805 | https://lcsc.com/product-detail/Multilayer-Ceramic-Capacitors-MLCC-SMD-SMT_muRata_GRM21BR61C106KE15L_10uF-106-10-16V_C77075.html | 0805 | X5R | ± 10% | 16V | Murata Electronics
C12 | Ceramic Capacitor, SMD | 1 | C77075 | 10uF | JLCPCB:C0805 | https://lcsc.com/product-detail/Multilayer-Ceramic-Capacitors-MLCC-SMD-SMT_muRata_GRM21BR61C106KE15L_10uF-106-10-16V_C77075.html | 0805 | X5R | ± 10% | 16V | Murata Electronics
C13 | Ceramic Capacitor, SMD | 1 | C52923 | 1uF | JLCPCB:C0402 | https://lcsc.com/product-detail/Multilayer-Ceramic-Capacitors-MLCC-SMD-SMT_SAMSUNG_CL05A105KA5NQNC_1uF-105-10-25V_C52923.html | 0402 | X5R | ± 10% | 25V | Samsung Electro-Mechanics
C14 | Ceramic Capacitor, SMD | 1 | C52923 | 1uF | JLCPCB:C0402 | https://lcsc.com/product-detail/Multilayer-Ceramic-Capacitors-MLCC-SMD-SMT_SAMSUNG_CL05A105KA5NQNC_1uF-105-10-25V_C52923.html | 0402 | X5R | ± 10% | 25V | Samsung Electro-Mechanics
C15 | Ceramic Capacitor, SMD | 1 | C1525 | 100nF | JLCPCB:C0402 | https://lcsc.com/product-detail/Multilayer-Ceramic-Capacitors-MLCC-SMD-SMT_SAMSUNG_CL05B104KO5NNNC_100nF-104-10-16V_C1525.html | 0402 | X7R | ± 10% | 16V | Samsung Electro-Mechanics
C16 | Ceramic Capacitor, SMD | 1 | C77075 | 10uF | JLCPCB:C0805 | https://lcsc.com/product-detail/Multilayer-Ceramic-Capacitors-MLCC-SMD-SMT_muRata_GRM21BR61C106KE15L_10uF-106-10-16V_C77075.html | 0805 | X5R | ± 10% | 16V | Murata Electronics
C17 | Ceramic Capacitor, SMD | 1 | C1548 | 15pF | JLCPCB:C0402 | https://lcsc.com/product-detail/Multilayer-Ceramic-Capacitors-MLCC-SMD-SMT_15pF-150-5-50V_C1548.html | 0402 | C0G | ± 5% | 50V | FH (Guangdong Fenghua Advanced Tech)
C18 | Ceramic Capacitor, SMD | 1 | C1548 | 15pF | JLCPCB:C0402 | https://lcsc.com/product-detail/Multilayer-Ceramic-Capacitors-MLCC-SMD-SMT_15pF-150-5-50V_C1548.html | 0402 | C0G | ± 5% | 50V | FH (Guangdong Fenghua Advanced Tech)
C19 | Ceramic Capacitor, SMD | 1 | C52923 | 1uF | JLCPCB:C0402 | https://lcsc.com/product-detail/Multilayer-Ceramic-Capacitors-MLCC-SMD-SMT_SAMSUNG_CL05A105KA5NQNC_1uF-105-10-25V_C52923.html | 0402 | X5R | ± 10% | 25V | Samsung Electro-Mechanics
C20 | Ceramic Capacitor, SMD | 1 | C1525 | 100nF | JLCPCB:C0402 | https://lcsc.com/product-detail/Multilayer-Ceramic-Capacitors-MLCC-SMD-SMT_SAMSUNG_CL05B104KO5NNNC_100nF-104-10-16V_C1525.html | 0402 | X7R | ± 10% | 16V | Samsung Electro-Mechanics
D1 | Schottky Diode | 1 | C8598 | B5819WSL | JLCPCB:SOD-123_L2.7-W1.6-LS3.7-RD-1 | https://lcsc.com/product-detail/Schottky-Barrier-Diodes-SBD_B5819W-SL_C8598.html | SOD-123 |  |  |  | Jiangsu Changjing Electronics Technology Co., Ltd.
D2 | Schottky Diode | 1 | C8598 | B5819WSL | JLCPCB:SOD-123_L2.7-W1.6-LS3.7-RD-1 | https://lcsc.com/product-detail/Schottky-Barrier-Diodes-SBD_B5819W-SL_C8598.html | SOD-123 |  |  |  | Jiangsu Changjing Electronics Technology Co., Ltd.
J1 | Right Angle, Type-C, SMD, USB Connector | 1 | C165948 | TYPE-C-31-M-12 | JLCPCB:USB-C_SMD-TYPE-C-31-M-12_1 | https://lcsc.com/product-detail/USB-Type-C_Korean-Hroparts-Elec-TYPE-C-31-M-12_C165948.html
J2 | Wire To Board Connector, Surface Mount, Vertical | 1 | C133062 | BM08B-GHS-TBT(LF)(SN) | JLCPCB:CONN-SMD_BM08B-GHS-TBT-LF-SN | https://lcsc.com/product-detail/Wire-To-Board-Wire-To-Wire-Connector_JST-Sales-America-BM08B-GHS-TBT-LF-SN_C133062.html | SMD,P=1.25mm |  |  |  | JST
J3 | Wire To Board Connector, Surface Mount, Vertical | 1 | C133062 | BM08B-GHS-TBT(LF)(SN) | JLCPCB:CONN-SMD_BM08B-GHS-TBT-LF-SN | https://lcsc.com/product-detail/Wire-To-Board-Wire-To-Wire-Connector_JST-Sales-America-BM08B-GHS-TBT-LF-SN_C133062.html | SMD,P=1.25mm |  |  |  | JST
J5 | Vertical ZIF connector, 12P, P=0.5mm, SMD | 1 | C262499 | AFC11-S12ICA-00 | JLCPCB:CONN-SMD-12P_AFC11-S12ICA-00 | https://lcsc.com/product-detail/Others_JUSHUO-AFC11-S12ICA-00_C262499.html | SMD,P=0.5mm |  |  |  | JUSHUO
Q1 | Bipolar Transistor (BJT), SMD | 1 | C2146 | S8050 | JLCPCB:SOT-23-3_L3.0-W1.7-P0.95-LS2.9-BR | https://lcsc.com/product-detail/Transistors-NPN-PNP_S8050-200-350_C2146.html |  |  |  |  | Jiangsu Changjing Electronics Technology Co., Ltd.
R1 | Thick Film Resistor, SMD | 1 | C23186 | 5.1k | JLCPCB:R0603 | https://lcsc.com/product-detail/Chip-Resistor-Surface-Mount-UniOhm_5-1KR-5101-1_C23186.html | 0603 | ±100ppm/℃ | ± 1% | 75V | UNI-ROYAL(Uniroyal Elec)
R2 | Thick Film Resistor, SMD | 1 | C23186 | 5.1k | JLCPCB:R0603 | https://lcsc.com/product-detail/Chip-Resistor-Surface-Mount-UniOhm_5-1KR-5101-1_C23186.html | 0603 | ±100ppm/℃ | ± 1% | 75V | UNI-ROYAL(Uniroyal Elec)
R3 | Thick Film Resistor, SMD | 1 | C25105 | 33 | JLCPCB:R0402 | https://lcsc.com/product-detail/Chip-Resistor-Surface-Mount-UniOhm_33R-33R0-1_C25105.html | 0402 | ±100ppm/℃ | ± 1% | 50V | UNI-ROYAL(Uniroyal Elec)
R4 | Thick Film Resistor, SMD | 1 | C25105 | 33 | JLCPCB:R0402 | https://lcsc.com/product-detail/Chip-Resistor-Surface-Mount-UniOhm_33R-33R0-1_C25105.html | 0402 | ±100ppm/℃ | ± 1% | 50V | UNI-ROYAL(Uniroyal Elec)
R6 | Thick Film Resistor, SMD | 1 | C11702 | 1k | JLCPCB:R0402 | https://lcsc.com/product-detail/Chip-Resistor-Surface-Mount-UniOhm_1KR-1001-1_C11702.html | 0402 | ±100ppm/℃ | ± 1% | 50V | UNI-ROYAL(Uniroyal Elec)
R7 | Thick Film Resistor, SMD | 1 | C11702 | 1k | JLCPCB:R0402 | https://lcsc.com/product-detail/Chip-Resistor-Surface-Mount-UniOhm_1KR-1001-1_C11702.html | 0402 | ±100ppm/℃ | ± 1% | 50V | UNI-ROYAL(Uniroyal Elec)
R8 | Thick Film Resistor, SMD | 1 | C25079 | 120 | JLCPCB:R0402 | https://lcsc.com/product-detail/Chip-Resistor-Surface-Mount-UniOhm_120R-1200-1_C25079.html | 0402 | ±100ppm/℃ | ± 1% | 50V | UNI-ROYAL(Uniroyal Elec)
R9 | Thick Film Resistor, SMD | 1 | C25744 | 10k | JLCPCB:R0402 | https://lcsc.com/product-detail/Chip-Resistor-Surface-Mount-UniOhm_10KR-1002-1_C25744.html | 0402 | ±100ppm/℃ | ± 1% | 50V | UNI-ROYAL(Uniroyal Elec)
R10 | Thick Film Resistor, SMD | 1 | C25744 | 10k | JLCPCB:R0402 | https://lcsc.com/product-detail/Chip-Resistor-Surface-Mount-UniOhm_10KR-1002-1_C25744.html | 0402 | ±100ppm/℃ | ± 1% | 50V | UNI-ROYAL(Uniroyal Elec)
R11 | Thick Film Resistor, SMD | 1 | C17714 | 47 | JLCPCB:R0805 | https://lcsc.com/product-detail/Chip-Resistor-Surface-Mount-UniOhm_47R-47R0-1_C17714.html | 0805 | ±100ppm/℃ | ± 1% | 150V | UNI-ROYAL(Uniroyal Elec)
R12 | Thick Film Resistor, SMD | 1 | C25879 | 2.2k | JLCPCB:R0402 | https://lcsc.com/product-detail/Chip-Resistor-Surface-Mount-UniOhm_2-2KR-2201-1_C25879.html | 0402 | ±100ppm/℃ | ± 1% | 50V | UNI-ROYAL(Uniroyal Elec)
R13 | Thick Film Resistor, SMD | 1 | C25744 | 10k | JLCPCB:R0402 | https://lcsc.com/product-detail/Chip-Resistor-Surface-Mount-UniOhm_10KR-1002-1_C25744.html | 0402 | ±100ppm/℃ | ± 1% | 50V | UNI-ROYAL(Uniroyal Elec)
SW1 | Push Button | 1 | C318884 | TS-1187A-B-A-B | JLCPCB:SW-SMD_4P-L5.1-W5.1-P3.70-LS6.5-TL_H1.5 | https://lcsc.com/product-detail/Tactile-Switches_XKB-Enterprise-TS-1187-B-A-A_C318884.html |  |  |  |  | XKB Connection
U1 | LDO voltage regulator | 1 | C51118 | AP2112K-3.3 | JLCPCB:SOT-25-5_L2.9-W1.6-P0.95-LS2.8-BL | https://lcsc.com/product-detail/Low-Dropout-Regulators-LDO_DIODES_AP2112K-3-3TRG1_AP2112K-3-3TRG1_C51118.html |  |  |  |  | Diodes Incorporated
U2 | 32Mbit / 4MiB Serial Flash Memory | 1 | C179173 | W25Q32JVSSIQ | JLCPCB:SOIC-8_L5.3-W5.3-P1.27-LS8.0-BL | http://www.winbond.com/resource-files/w25q32jv%20revg%2003272018%20plus.pdf | SOIC-8-208mil |  |  |  | Winbond Elec
U3 | Microcontroller | 1 | C2040 | RP2040 | JLCPCB:LQFN-56_L7.0-W7.0-P0.4-EP | https://www.lcsc.com/datasheet/C2040.pdf | LQFN-56 |  |  |  | Raspberry Pi
U4 | 50Mbps Half-Duplex Transceiver, RS485/RS422 | 1 | C2671361 | THVD1450DR | JLCPCB:SOIC-8_L4.9-W3.9-P1.27-LS6.0-BL | https://www.ti.com/lit/ds/symlink/thvd1450.pdf | SOIC-8 |  |  |  | Texas Instruments
Y1 | Crystal Oscillator, 12 MHz | 1 | C20625731 | ABM8-272-T3 | JLCPCB:CRYSTAL-SMD_4P-L3.2-W2.5-BL | https://www.lcsc.com/datasheet/C20625731.pdf | SMD3225-4P |  |  |  | Abracon LLC

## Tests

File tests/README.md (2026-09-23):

# Tests

All tests carried out are described in this directory. The tests are split into the different phases explained in the [Roadmap](../README.md#roadmap). The respective subfolders contain dedicated test code, that also may be used in the final software.

| Folder | Description |
|---|---|
| [`phase-1.1-display-performance/`](phase-1.1-display-performance/) | Single GC9A01 dev board on a Pico, target 60 FPS |
| [`phase-2.1-rs485-test-master/`](phase-2.1-rs485-test-master/) | Master code to send test-packets over RS485 |
| [`phase-2.1-rs485-test-slave/`](phase-2.1-rs485-test-slave/) | Slave code to receive and process test-packets over RS485 |
| [`phase-3.1-protocol-design/`](phase-3.1-protocol-design/) | Protocol definitions and unit test code |
| [`phase-3.2-protocol-test-master/`](phase-3.2-protocol-test-master/) | Master code broadcasting the state protocol to all 72 nodes |
| [`phase-3.2-protocol-test-slave/`](phase-3.2-protocol-test-slave/) | Slave code receiving the broadcast and rendering its own node |

<details>
<summary><strong>1.1 Display performance</strong></summary>

### Objective

Drive one GC9A01 round LCD dev board from a Raspberry Pi Pico on a breadboard, sustaining 60 FPS.

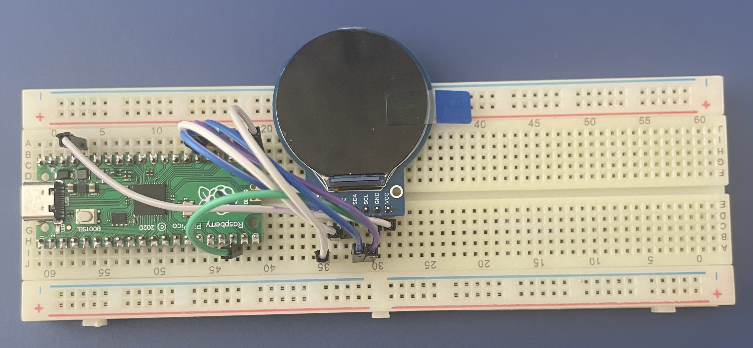
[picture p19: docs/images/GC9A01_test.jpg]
GC9A01 Test


### Wiring

| Signal | GPIO | Pin Nr.
|---|---|---|
| VCC | 3V3 (OUT)| 36 |
| GND | GND | 38|
| SCL/SCLK | GP18 | 24 |
| SDA/MOSI | GP19 | 25 |
| CS | GP20 | 26 |
| DC | GP17 | 22 |
| RST | GP16 | 21 |

### Findings

As it turns out, actually getting 60 FPS is more difficult than anticipated. It comes down to the size of a single frame and the transfer speed of the bus. The display has 240 × 240 pixels and is set to 16-bit (2 bytes) color by default, so a single frame needs 240 × 240 × 2 = 115.2 kB of data. To achieve 60 FPS, that frame needs to be sent 60 times per second, which works out to 115.2 kB × 60 = 6912 kB/s, or 55'296 kbit/s (about 55.3 Mbit/s). Since every bit occupies one clock tick during transmission, sustaining 60 FPS requires transfer speed of at least roughly 56 MHz.

The data is sent over the SPI bus, which is wired to the peripheral clock of the RP2040. To achieve an effective transfer speed of 56 MHz, the actual peripheral clock needs to run at least double that, because SPI signals are represented as a square wave, pulling the line high and then low each take one clock tick, so sending a single bit actually costs two clock ticks. By default, the peripheral clock is wired to the USB clock, which runs at 48 MHz, which is far too slow to reach 60 FPS.

To fix this, the clock_config() function from the RP2040 SDK can be used to wire the peripheral (SPI) clock to the CPU clock instead. By default, the RP2040's system clock runs at 125 MHz, but since this project uses the earlephilhower core (set in platformio.ini), the system clock is automatically overclocked to 133 MHz. This value can be changed in platformio.ini if needed.

In the LovyanGFX config file LGFX_Config.hpp, the requested transfer speed is set via a register write (freq_write). It's important to know that the actual achievable transfer speed can only ever be the source clock divided by an even integer (2, 4, 6, …), so the frequency requested in LGFX_Config.hpp gets rounded to the nearest matching value. For example, requesting 70 MHz against a 133 MHz source clock actually yields 133 / 2 = 66.5 MHz, since dividing by 2 gives the closest match to the requested frequency.

The `freq_write` property was set to 70 MHz so as not to overwhelm the GC9A01 display controller, even though higher frequencies would probably work fine. As shown above, this rounds down to an actual SPI speed of 66.5 MHz. To sustain 60 FPS, each frame has a time budget of at most 16.6 ms to be drawn and pushed over the bus. As shown in the first calculation, a full frame's payload is 115.2 kB (921.6 kbit), which at our transfer speed of 66.5 MHz would take roughly 13.86 ms to push over SPI. That alone consumes most of the per-frame budget, and on top of pushing the data, the frame also needs to be drawn, which costs additional CPU time. So the per-frame budget splits into drawing time and push time, and together they must not exceed 16.6 ms.

Clearly the push time needed to be cut down, since the remaining 2.74 ms would never be enough to draw an entire frame. The first lever is sprites: LovyanGFX lets a frame be fully buffered in RAM and then pushed as a whole, which is much faster than drawing directly to the display. The second, bigger lever is reducing the payload itself, i.e. the actual amount of data pushed. Since only the two clock hands move, most pixels stay unchanged frame to frame, so only the pixels that actually change need to be sent. This is done by forming a bounding box around each hand's previous and next position. Tests have shown that this shrinks the payload from 115.2 kB (full frame) to ~15 kB, bringing the average push time down to 3 ms (measured) at most and leaving around 13 ms for computation.

The clock hands are drawn with `drawWedgeLine()`, which produces a clean anti-aliased (AA) line. Because of the AA, though, it's computationally expensive: it relies on floating-point math, and the RP2040 has no hardware FPU. Calling `drawWedgeLine()` twice per frame (once per hand) pushed drawing time to well over 20 ms. To bring that down, each hand is now drawn once at startup, then rotated into place every frame with `pushRotateZoom()`. Combined with the payload reduction, this pushed the frame rate to 250 FPS, far more than the display could ever show. The catch is that AA is baked in only once, in that first frame, so it looks slightly off once rotated. `pushRotateZoomWithAA()` fixes this: it keeps some AA quality while still costing much less than calling `drawWedgeLine()` fresh every frame.

### How to test
- Build/flash the PlatformIO project in `phase-1.1-display-performance/` -> `pio run -d ./tests/phase-1.1-display-performance -t upload`
- Start serial monitor ->  `pio device monitor -d ./tests/phase-1.1-display-performance`
- The clock hands should appear and start rotating
- observe the reported FPS via serial monitor. It should be around 80 FPS.
- Occasionally a flickering can be observed. This might be due to bad signal integrity on a breadboard and will improve on a PCB.

### Results
```bash
FPS:86.4  draw avg:8.90ms max:9.37ms  push avg:2.65ms max:3.27ms  [prev report: 1.33ms, payload: 17 kB]
FPS:89.4  draw avg:9.09ms max:9.39ms  push avg:2.07ms max:2.85ms  [prev report: 1.09ms, payload: 11 kB]
FPS:87.4  draw avg:8.84ms max:9.47ms  push avg:2.57ms max:3.27ms  [prev report: 1.06ms, payload: 19 kB]
FPS:85.8  draw avg:9.37ms max:9.77ms  push avg:2.26ms max:2.87ms  [prev report: 1.04ms, payload: 19 kB]
FPS:87.7  draw avg:8.86ms max:9.38ms  push avg:2.52ms max:3.27ms  [prev report: 1.04ms, payload: 12 kB]
FPS:89.2  draw avg:9.08ms max:9.52ms  push avg:2.10ms max:2.85ms  [prev report: 1.08ms, payload: 18 kB]
FPS:86.4  draw avg:8.88ms max:9.35ms  push avg:2.67ms max:3.27ms  [prev report: 1.03ms, payload: 20 kB]
FPS:87.3  draw avg:9.23ms max:9.80ms  push avg:2.19ms max:2.92ms  [prev report: 1.05ms, payload: 8 kB]
FPS:86.9  draw avg:9.09ms max:10.01ms  push avg:2.38ms max:3.16ms  [prev report: 1.07ms, payload: 22 kB]
FPS:86.5  draw avg:8.93ms max:9.34ms  push avg:2.61ms max:3.27ms  [prev report: 1.06ms, payload: 15 kB]
FPS:89.5  draw avg:9.10ms max:9.36ms  push avg:2.05ms max:2.86ms  [prev report: 1.01ms, payload: 14 kB]
FPS:87.2  draw avg:8.83ms max:9.44ms  push avg:2.61ms max:3.27ms  [prev report: 1.06ms, payload: 20 kB]
```

</details>

<details>
<summary><strong>1.2 power measurement</strong></summary>

### Objective

Measure how much power a Raspberry Pi Pico with an attached GC9A01 display and RS485 communication draws

### Results

The following average values were recorded:
- 5.1 V
- 0.06 A
- 0.3 W

</details>

<details>
<summary><strong>2.1 RS485 link</strong></summary>

### Objective

Test the RS485 connection by having a sender and a receiver talk to each other. The goal is to send a barebone packet via RS485 to the receiver, which then uses the received data to display something. The receiver side reuses the same display test setup as in phase 1.1.

### Wiring

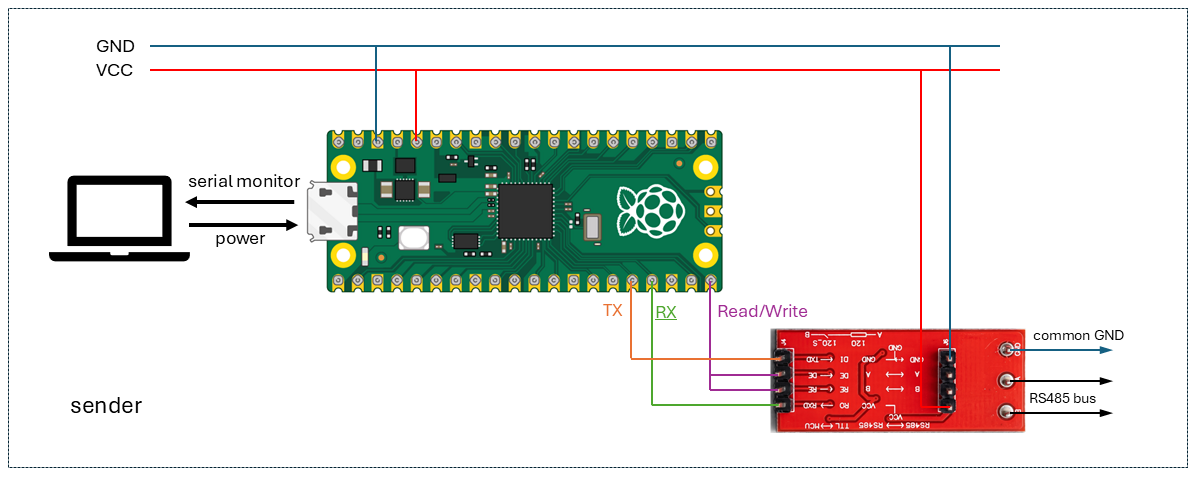
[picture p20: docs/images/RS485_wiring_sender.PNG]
RS485 Wiring - Sender

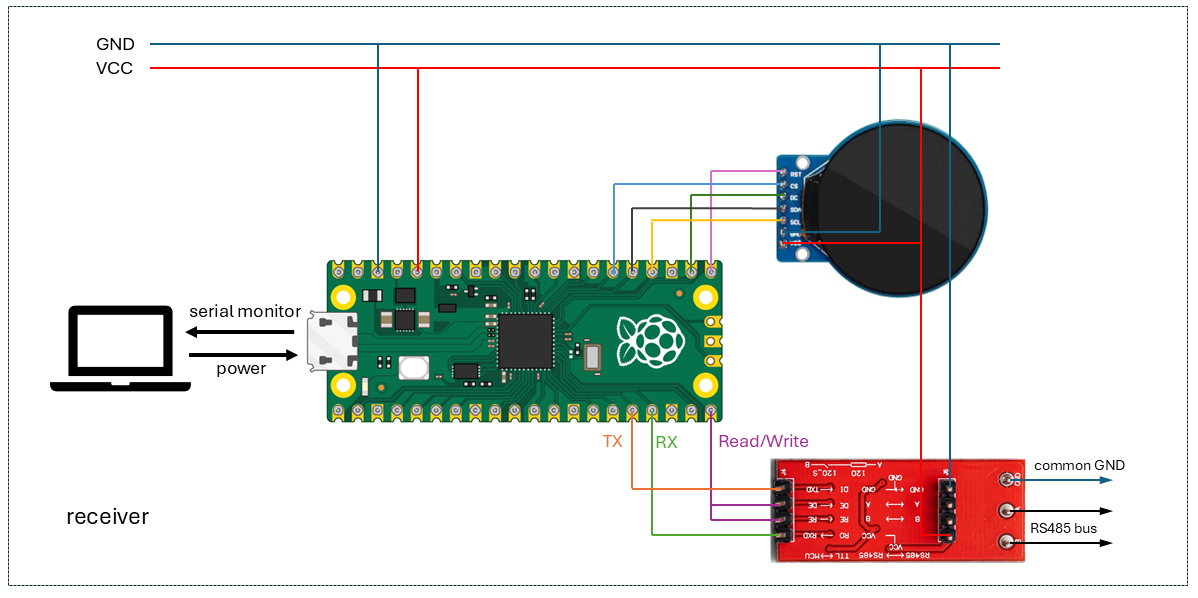
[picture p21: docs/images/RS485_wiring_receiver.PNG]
RS485 Wiring - Receiver


| Sender Module / Line | Connected Sender Pico Pin | Function  | $\leftrightarrow$ | Receiver Module / Line | Connected Receiver Pico Pin | Function |
| :--- | :--- | :--- | :---: | :--- | :--- | :--- |
| **RS485 Module (VCC)** | VBUS / 3V3 | Power Supply | **$---$** | **RS485 Module (VCC)** | VBUS / 3V3 | Power Supply |
| **RS485 Module (GND)** | Any GND Pin | Common Ground | **$---$** | **RS485 Module (GND)** | Any GND Pin | Common Ground |
| **RS485 Module (RO / RXD)** | GP13 (UART0 RX) | Data Receive | **$---$** | **RS485 Module (RO / RXD)** | GP13 (UART0 RX) | Data Receive |
| **RS485 Module (DI / TXD)** | GP12 (UART0 TX) | Data Transmit | **$---$** | **RS485 Module (DI / TXD)** | GP12 (UART0 TX) | Data Transmit |
| **RS485 Module (DE & RE)** | GP15 | Direction (HIGH = Tx) | **$---$** | **RS485 Module (DE & RE)** | GP15 | Direction (LOW = Rx) |
| *None (Sender Only)* | *N/A* | *N/A* | **$---$** | **Display (VCC / Power)** | VBUS / 3V3 | Display Power Supply |
| *None (Sender Only)* | *N/A* | *N/A* | **$---$** | **Display (GND)** | Any GND Pin | Display Ground |
| *None (Sender Only)* | *N/A* | *N/A* | **$---$** | **Display (SCL / MOSI / etc.)**| *As documented in Phase 1* | Display SPI / Control Lines |

Both Picos are connected and powered by separate USB-C cables, so each can be watched on its own serial monitor. However, for RS485 to work reliably they need to share a common ground. The sender and receiver are connected by the RS485 data lines A & B and share a GND line. The Data Enable (DE) and Read Enable (RE) pins on the RS485 module control whether it is transmitting or reading. Both are tied together to GP15 on the Pico, and the mode is set by driving that GPIO HIGH or LOW. During this test the sender always drives it HIGH (transmitting) and the receiver always drives it LOW (reading).

### Findings

For testing, the following packet was used. It is essentially a simple C++ struct, but with a few quirks. By default, compilers add padding bytes between struct members to allow more efficient memory access. Since the sender and receiver must agree on this packet layout, it's essential that both are compiled identically. If one side ends up with different padding, the two sides disagree on the struct size and the packet can't be parsed correctly. The `#pragma pack(push, 1)` statement prevents the compiler from adding any padding, so the struct always uses the minimum number of bytes.

```cpp
#pragma pack(push, 1) 
struct ClockDataPacket {
    // --- Header ---
    uint8_t startByte1;      
    uint8_t startByte2;      
    uint32_t packetSequence; 
    
    // --- Payload ---
    char statusMessage[16]; 
    
    // --- Footer ---
    uint8_t xorChecksum;    
};
#pragma pack(pop)
```

The protocol has a fixed header and footer that stay the same regardless of the payload. The header starts with two sync bytes, always the distinct values 0xAA (10101010) and 0x55 (01010101). Written out in binary, these form a perfectly alternating bit pattern. The receiver waits for exactly this 0xAA-then-0x55 sequence before it starts reading a packet. This prevents data misalignment, and since the two values are distinct and unlikely to occur together by chance inside the payload, it forms a reliable framing marker. The `packetSequence` field increments with every packet sent, so missing or corrupted packets can be detected by gaps in the sequence.

The footer is a single `xorChecksum` byte used to verify the data arrived intact. It's calculated by running a bitwise XOR over the entire struct, excluding the checksum byte itself, independently on both the sender and the receiver. The sender stores its calculated value in the footer before transmitting, the receiver then recalculates the checksum on its end and compares the two. On a mismatch, the packet is discarded as corrupted. XOR is a simple, fast form of error detection that's sufficient for this use case. CRC-8 or CRC-16 would be more robust alternatives if needed.

As mentioned above, the receiver only starts reading the payload once it has seen both sync bytes in sequence. To make this reliable, it uses a state machine with three states: WAITING_FOR_SYNC1, WAITING_FOR_SYNC2, and READING_PAYLOAD. A state machine handles corrupted or misaligned input more robustly than nested if/else logic would.

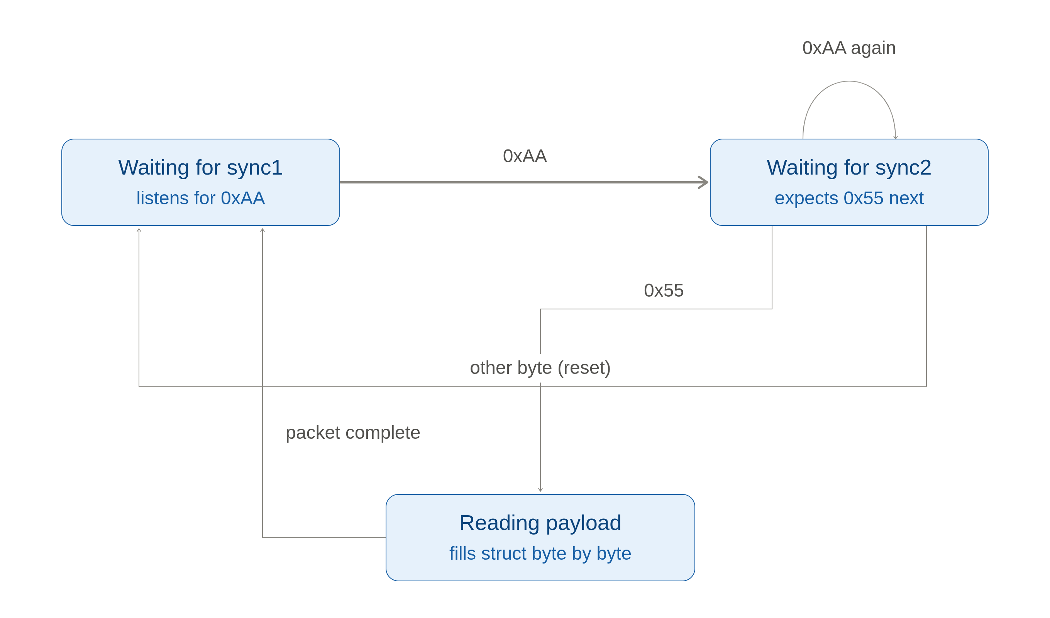
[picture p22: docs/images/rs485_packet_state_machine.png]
State machine


This protocol design can scale to the full array, but the packet *rate* grows quickly with it. The plan for the finished clock is to broadcast a small state instruction every frame, e.g. "point the clock hand at 30°", rather than a full image. To sustain 60 FPS across all 72 nodes, that works out to 72 × 60 = 4'320 packets per second. The packet used in this test is already 31 bytes, so at that rate we'd need 4'320 × 31 B ≈ 133.9 kB/s. The baud rate sets the theoretical ceiling on the bus: at 1 Megabaud with standard 8N1 UART framing (1 start bit + 8 data bits + 1 stop bit = 10 bits per byte), the maximum payload throughput is 1'000'000 / 10 = 100 kB/s. Higher baud rates are possible, but 1 Megabaud is a reasonable target, keeping in mind the achievable rate also depends on the actual length of the RS485 line. Either way, the required 133.9 kB/s already exceeds this ~100 kB/s ceiling. With today's packet size, the bus itself is the bottleneck before we even reach 72 nodes. The physical layout should be a daisy chain, with 120 Ω termination resistors at both ends of the bus, as is standard practice for RS485.

It's clear the packet size needs to shrink for a reliable link at this scale. This is something to keep in mind for Phase 3 (proving the state protocol on breadboards). A few approaches are worth considering:
- Make the receivers smarter, so less data needs to be sent per update. Probably best avoided: it pushes more logic onto every node's firmware, which then has to be kept in sync across all of them.
- Use different packet types for different purposes: one for setting up the clock's initial state, small packets for incremental state updates, and an entirely different packet format for other applications, like a snake game.

### How to test
- Build and flash the PlatformIO projects in `phase-2.1-rs485-test-master` and `phase-2.1-rs485-test-slave`.
- Connect the slave to the PC with a USB-C cable and open the serial monitor. It should indicate that the connection was successful.
- Connect the master to a simple power source via USB-C or a PC
- The master should start sending packets over RS485. 
- The serial monitor of the slave should display each packet that it received.
- The display should show the instructions it received over RS485

### Results

Serial monitor shouls show something like this
```bash
RS485 Slave Initializing...
Slave ready. Listening for packets...
[SUCCESS] Pkt #354 | Uptime: 7680ms | Angles: 113.6/208.0 deg | Msg: Message
[SUCCESS] Pkt #355 | Uptime: 7696ms | Angles: 113.9/209.6 deg | Msg: Message
[SUCCESS] Pkt #356 | Uptime: 7712ms | Angles: 114.2/211.2 deg | Msg: Message
[SUCCESS] Pkt #357 | Uptime: 7728ms | Angles: 114.5/212.8 deg | Msg: Message
[SUCCESS] Pkt #358 | Uptime: 7744ms | Angles: 114.8/214.4 deg | Msg: Message
[SUCCESS] Pkt #359 | Uptime: 7760ms | Angles: 115.2/216.0 deg | Msg: Message
```

</details>

<details>
<summary><strong>3.1 protocol design</strong></summary>

### Objective

Design the state protocol that can carry all the necessary data over the RS485 bus.

### Considerations

It was decided not to add support for generic drawing methods (e.g. for a snake game) for now, since this would add substantial complexity. Instead, priority lies on the Clock and Widget modes. To support both, it was decided not to use one fixed protocol, but to split communication into two phases: Init and Update. Init is a heavier protocol that carries configuration data, such as the color and length of the clock hands or the background image of a widget. It can be triggered by the master controller, which interrupts all other RS485 communication and thereby frees up enough bandwidth to push the heavier config data. The Update protocol, on the other hand, carries updated angles for clocks or updated values for widgets. These packets are smaller than the Init data, since the goal is to broadcast them at 60 Hz.

To keep packet sizes as small as possible, I defined four distinct protocol types: `CLOCK_INIT`, `WIDGET_INIT`, `CLOCK_UPDATE`, and `WIDGET_UPDATE`. The protocol header includes an enum, shared by master and slave, that identifies which protocol type is being transmitted.

The protocol header design was already discussed in phase 2. However, the sync bytes `0xAA` and `0x55` proposed there, generate more overhead than necessary. Our protocol therefore implements Consistent Overhead Byte Stuffing (COBS) instead. COBS works by finding every `0x00` byte in the data and replacing it with a count of how many bytes lie until the next `0x00`. It also prepends one extra byte at the start of the packet, indicating the distance to the first `0x00`. This guarantees the encoded payload never contains a `0x00` byte, so that byte can reliably be used as an end-of-packet marker. This also fixes a problem with the old method, where `0xAA` and `0x55` could still appear inside the payload by chance and cause data misalignment. COBS also has one byte less overhead than the two sync bytes it replaces. A nice property of COBS is that a single `0x00` byte marks both the end of the current packet and the start of the next one.

The XOR checksum, already implemented in phase 2, verifies that all data was transmitted correctly. If the checksum doesn't match, the receiver discards everything that follows until it sees the next `0x00`, which marks the end of the corrupted packet. So it knows the following byte starts a new packet. The header also includes the packetSequence field from phase 2, downgraded from `uint32_t` to `uint8_t` to save three bytes. It's simply a counter rolling from 0 to 255, which should be enough to detect missing packets.

As mentioned, all other RS485 communication is halted while the master sends a `CLOCK_INIT` or `WIDGET_INIT` packet, to prevent a bus overload. `CLOCK_UPDATE` packets are sent 60 times per second to ensure smooth animations. To make sure all slaves receive their data at the same time, each `CLOCK_UPDATE` packet carries the update data for all 72 nodes at once. This is far more efficient than sending individual packets, which would multiply the protocol overhead drastically. The data sits in a continuous array and is read by each slave at the position matching its address. Addresses will be assigned automatically later on. `WIDGET_UPDATE` packets, by contrast, will most likely be sent only periodically, and never target all nodes at once. For this reason, the protocol header includes a target-node byte that specifies which address a packet should be sent to.

### Frame Layout

Putting all of the above together, a frame looks like this before COBS is applied:

```
[command][targetNode][sequence][ ...payload... ][xorChecksum]
   0          1          2         3 .. N-1          N
   |______ header ______|                            |
                                              covers bytes 0..N-1
```

To safely transmit this over the RS485 bus, the entire structure is COBS-encoded and terminated with a single `0x00` delimiter:

```
[ COBS( header + payload + checksum ) ][ 0x00 ]
```

Every part of a frame is described by a C++ struct in `protocol.h`. Master and slave are compiled for different devices, so each struct is wrapped in `#pragma pack(push, 1)`. This stops the compiler from adding padding bytes between the members and keeps the layout identical on both ends. Each packed struct is also followed by a `static_assert()` on its size. If a struct ever ends up a different size than expected, the code simply won't compile.

`protocol.h` offers two functions as its public API: `buildFrame()` and `parseFrame()`. Master and slave only ever need these two. Everything else in the file (COBS, checksum, structs) is just the machinery behind them.

The master calls `buildFrame()` and passes the following arguments:
- `cmd`: which type of packet to build, taken from the `CommandType` enum.
- `targetNode`: which slave the packet is meant for. Usually `0xFF` (`GLOBAL_BROADCAST_ID`) to address all nodes at once. Realistically only `CMD_WIDGET_UPDATE` needs a specific address, in the range 0..71.
- `sequence`: a counter the master increments with every packet, so the slave can spot gaps and detect dropped packets.
- `payload`: a pointer to the payload. The master builds it from the structs in `protocol.h` and passes the address. May be `nullptr` if `payloadLen` is 0.
- `payloadLen`: how many bytes of the payload to send. Most commands have a fixed size, so this is usually redundant, but `CMD_WIDGET_UPDATE` has a variable payload and needs it. Anything above `MAX_PAYLOAD_SIZE` (288 bytes) is rejected.
- `out`: the buffer to write the finished frame to.
- `outCap`: how big `out` is, purely to prevent an overflow. `MAX_ENCODED_FRAME` is always big enough.

`buildFrame()` puts together the header, payload and checksum, COBS-encodes the whole thing, appends the `0x00` delimiter and writes it to `out`. It returns how many bytes it wrote (delimiter included), or 0 if it failed. The master sends exactly that many bytes down the wire.

The slave calls `parseFrame()`, which does the opposite:
- `encoded`: a pointer to the encoded frame read from the bus, *without* the trailing `0x00`. The slave strips the delimiter before calling.
- `encodedLen`: how many bytes were read from the bus.
- `scratch`: a buffer owned by the slave that the frame is decoded into. The result points into this buffer instead of copying, so it has to stay untouched for as long as the frame is used.
- `scratchCap`: how big `scratch` is, again to prevent an overflow. `MAX_DECODED_FRAME` is always big enough.
- `out`: a `Frame` struct that gets filled in on success, giving the slave the header plus a pointer and length for the payload. It stays untouched if parsing fails.

`parseFrame()` doesn't just report success or failure. It returns a `ParseResult` naming the step that rejected the frame: COBS framing, minimum length, checksum, unknown command, payload length or target node. The checks run in that order, so the first one to fail is also the most basic problem. `parseResultName()` turns the result into readable text for the serial log.
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

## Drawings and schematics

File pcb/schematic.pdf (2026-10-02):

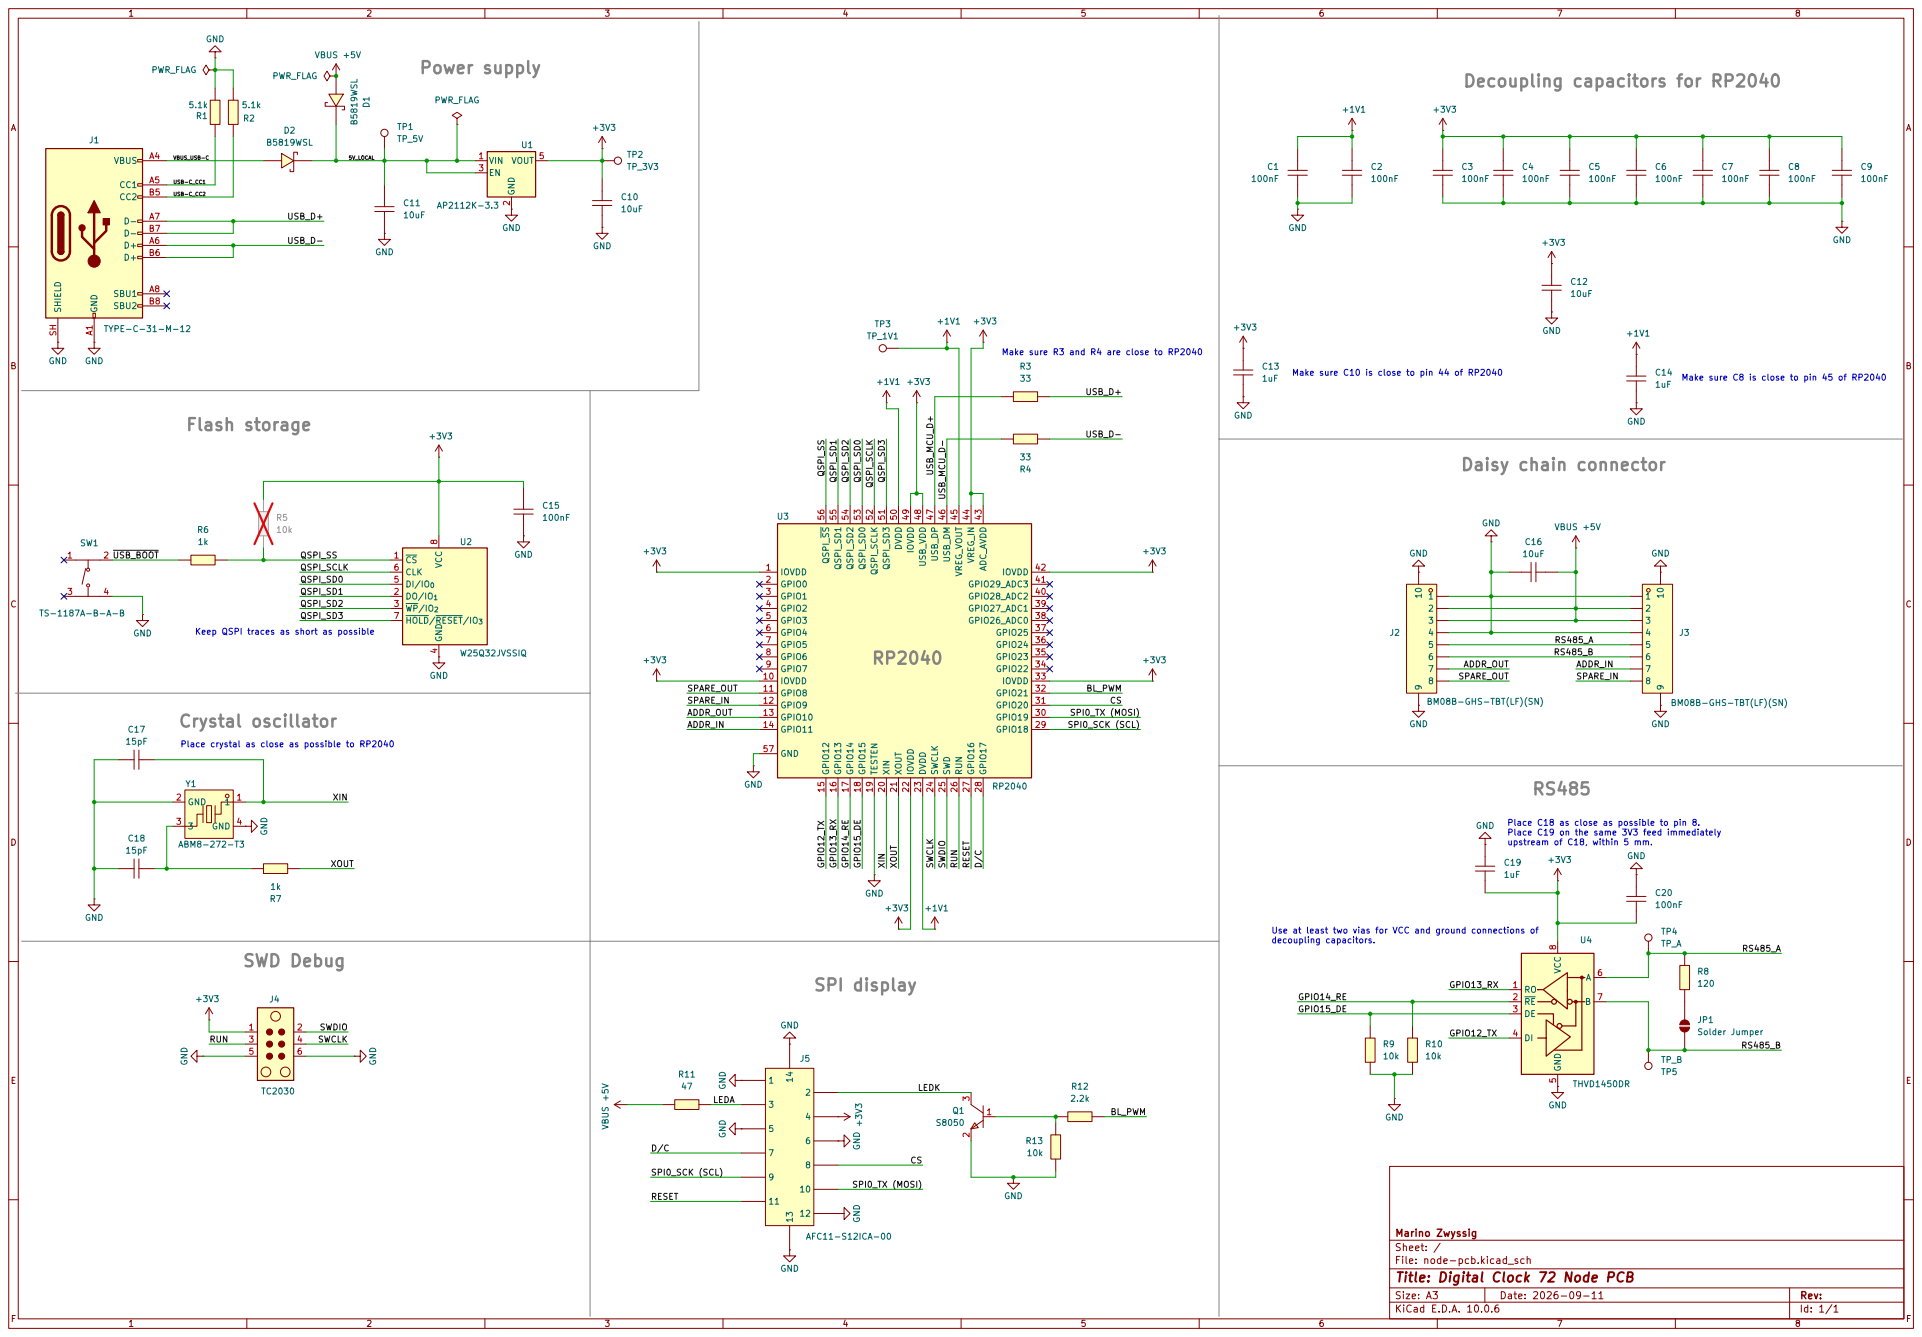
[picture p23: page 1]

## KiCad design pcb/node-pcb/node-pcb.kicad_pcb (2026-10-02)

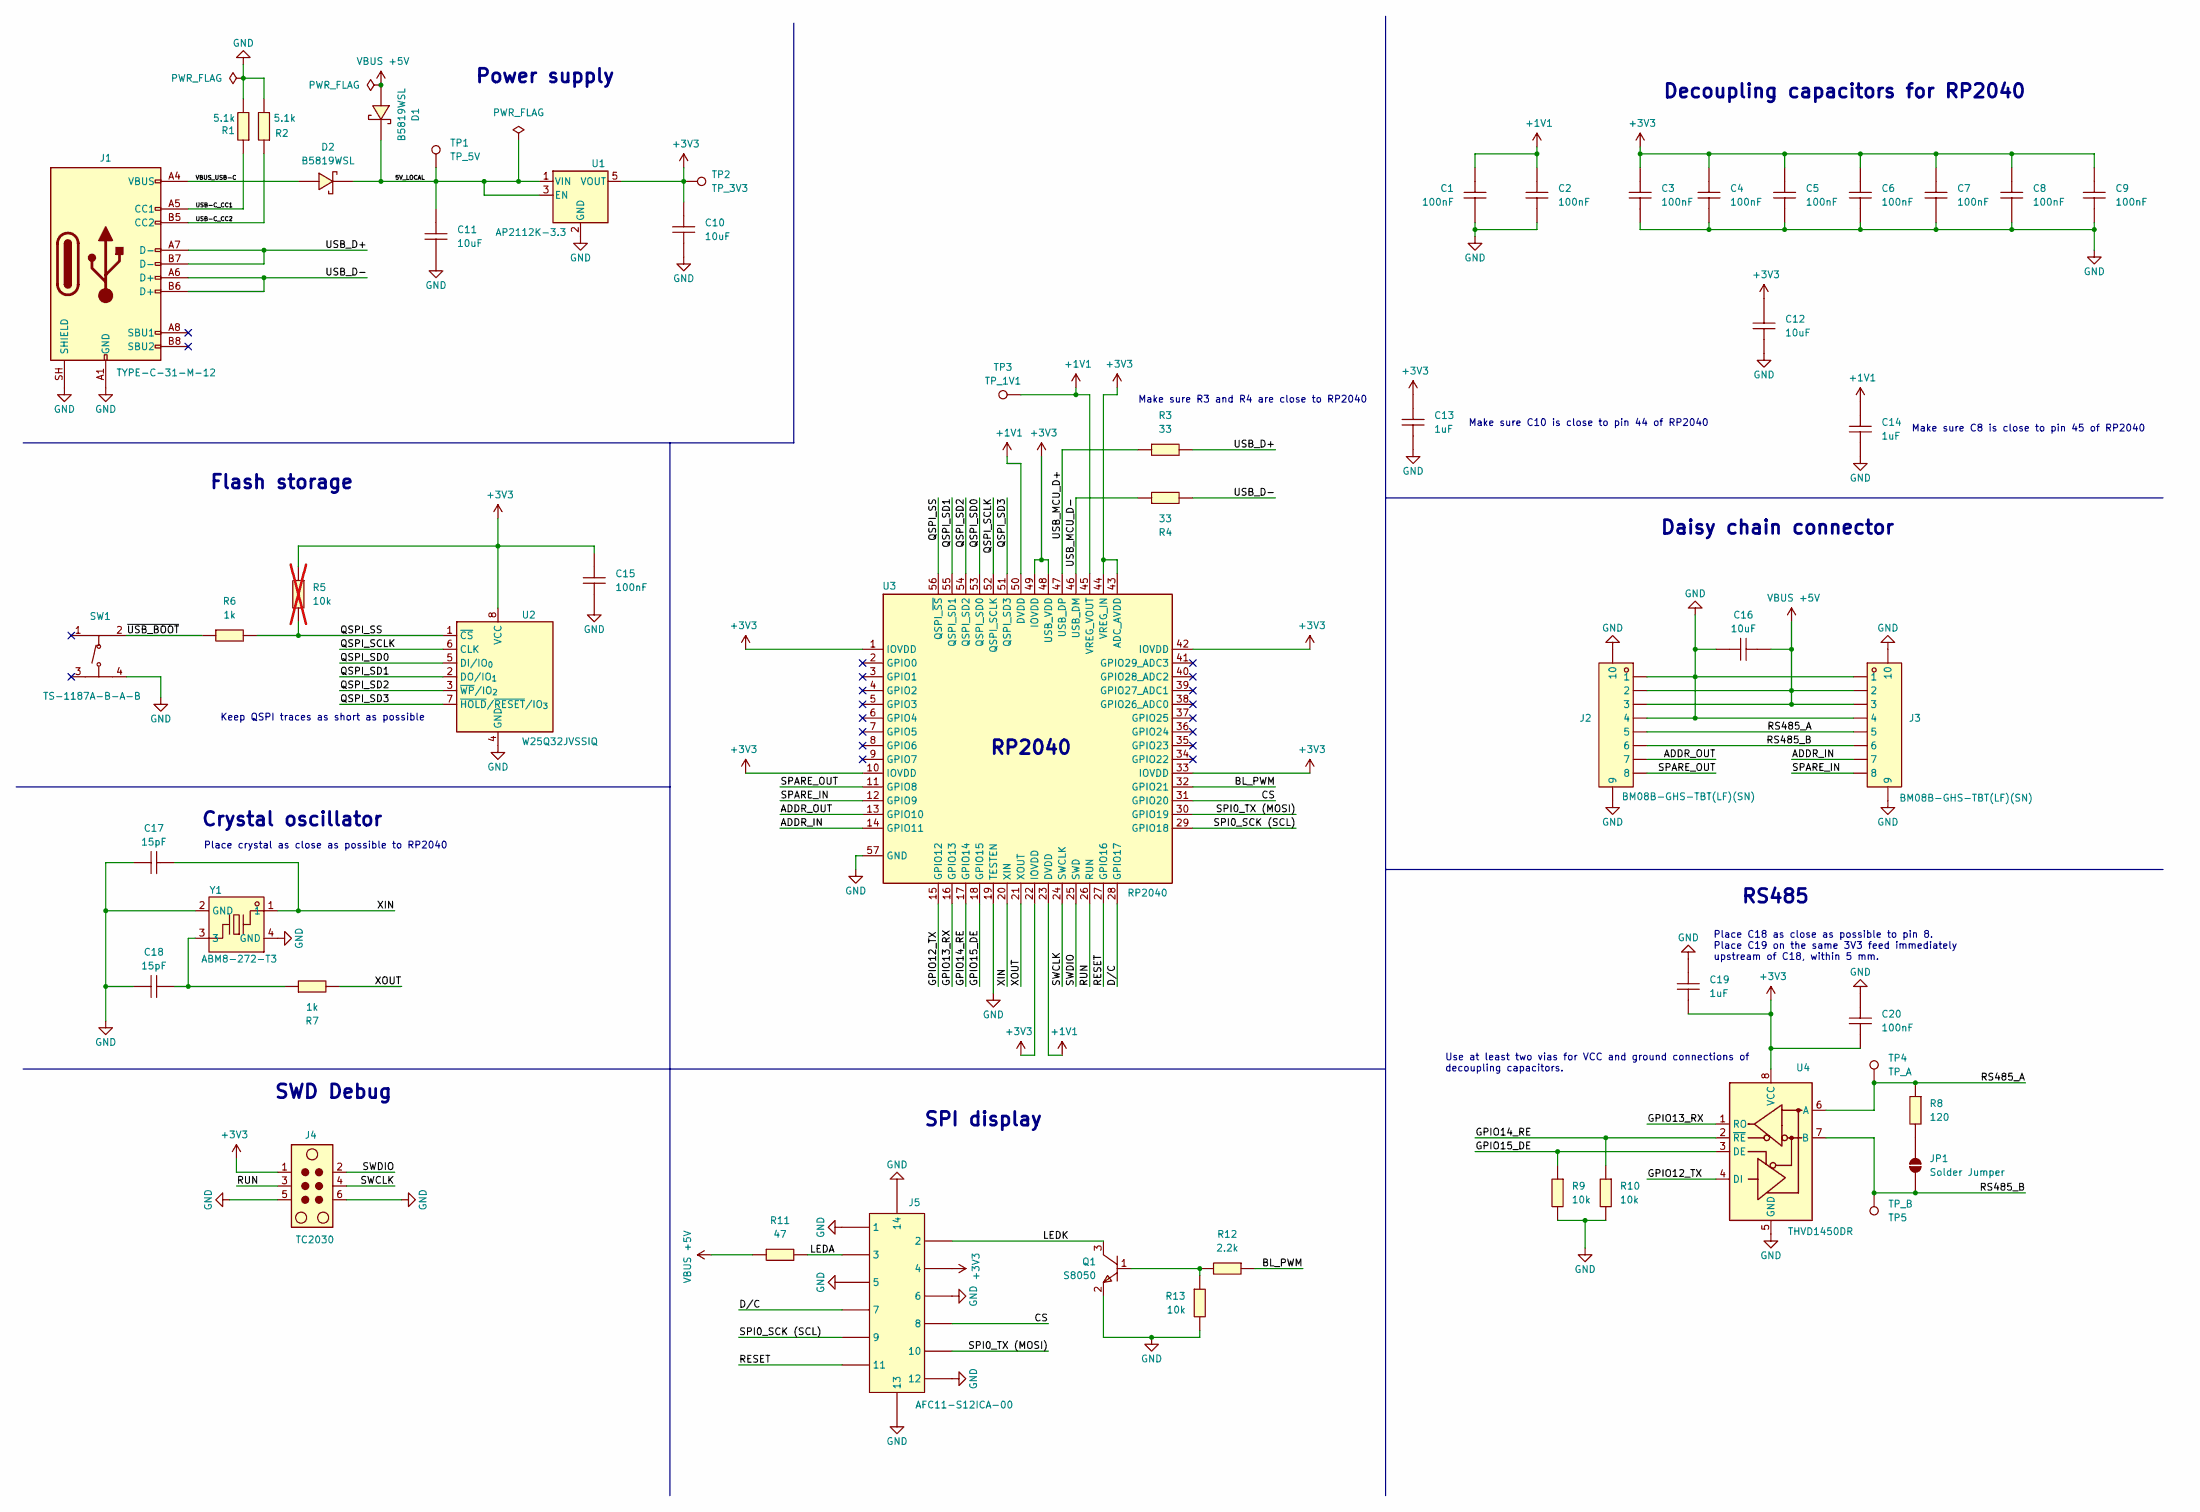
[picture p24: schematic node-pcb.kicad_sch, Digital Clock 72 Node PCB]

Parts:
C1, C2, C3, C4, C5, C6, C7, C8, C9, C15, C20: 100nF; C0402; tolerance ± 10%; voltage 16V; MPN CL05B104KO5NNNC; LCSC Part C1525
C10, C11, C12, C16: 10uF; C0805; tolerance ± 10%; voltage 16V; MPN GRM21BR61C106KE15L; LCSC Part C77075
C13, C14, C19: 1uF; C0402; tolerance ± 10%; voltage 25V; MPN CL05A105KA5NQNC; LCSC Part C52923
C17, C18: 15pF; C0402; tolerance ± 5%; voltage 50V; MPN 0402CG150J500NT; LCSC Part C1548
D1, D2: B5819WSL; SOD-123_L2.7-W1.6-LS3.7-RD-1; MPN B5819W SL; LCSC Part C8598
J1: TYPE-C-31-M-12; USB-C_SMD-TYPE-C-31-M-12_1; LCSC Part C165948
J2, J3: BM08B-GHS-TBT(LF)(SN); CONN-SMD_BM08B-GHS-TBT-LF-SN; MPN BM08B-GHS-TBT(LF)(SN); LCSC Part C133062
J4: TC2030; Tag-Connect_TC2030-IDC-NL_2x03_P1.27mm_Vertical
J5: AFC11-S12ICA-00; CONN-SMD-12P_AFC11-S12ICA-00; MPN AFC11-S12ICA-00; LCSC Part C262499
JP1: Solder Jumper; SolderJumper-2_P1.3mm_Open_RoundedPad1.0x1.5mm
Q1: S8050; SOT-23-3_L3.0-W1.7-P0.95-LS2.9-BR; MPN S8050 J3Y(RANGE:200-350); LCSC Part C2146
R1, R2: 5.1k; R0603; tolerance ± 1%; voltage 75V; MPN 0603WAF5101T5E; LCSC Part C23186
R3, R4: 33; R0402; tolerance ± 1%; voltage 50V; MPN 0402WGF330JTCE; LCSC Part C25105
R5: 10k; R0402; MPN 0402WGF1002TCE; LCSC Part C25744; not fitted
R6, R7: 1k; R0402; tolerance ± 1%; voltage 50V; MPN 0402WGF1001TCE; LCSC Part C11702
R8: 120; R0402; tolerance ± 1%; voltage 50V; MPN 0402WGF1200TCE; LCSC Part C25079
R9, R10, R13: 10k; R0402; tolerance ± 1%; voltage 50V; MPN 0402WGF1002TCE; LCSC Part C25744
R11: 47; R0805; tolerance ± 1%; voltage 150V; MPN 0805W8F470JT5E; LCSC Part C17714
R12: 2.2k; R0402; tolerance ± 1%; voltage 50V; MPN 0402WGF2201TCE; LCSC Part C25879
SW1: TS-1187A-B-A-B; SW-SMD_4P-L5.1-W5.1-P3.70-LS6.5-TL_H1.5; MPN TS-1187A-B-A-B; LCSC Part C318884
TP1: TP_5V; TestPoint_Pad_D1.0mm
TP2: TP_3V3; TestPoint_Pad_D1.0mm
TP3: TP_1V1; TestPoint_Pad_D1.0mm
TP4: TP_A; TestPoint_Pad_D1.0mm
TP5: TP_B; TestPoint_Pad_D1.0mm
U1: AP2112K-3.3; SOT-25-5_L2.9-W1.6-P0.95-LS2.8-BL; MPN AP2112K-3.3TRG1; LCSC Part C51118
U2: W25Q32JVSSIQ; SOIC-8_L5.3-W5.3-P1.27-LS8.0-BL; manufacturer_pn W25Q32JVSSIQ; LCSC Part C179173
U3: RP2040; LQFN-56_L7.0-W7.0-P0.4-EP; manufacturer_pn RP2040; LCSC Part C2040
U4: THVD1450DR; SOIC-8_L4.9-W3.9-P1.27-LS6.0-BL; manufacturer_pn THVD1450DR; LCSC Part C2671361
Y1: ABM8-272-T3; CRYSTAL-SMD_4P-L3.2-W2.5-BL; manufacturer_pn ABM8-272-T3; LCSC Part C20625731

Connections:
+1V1: C1.1, C2.1, C14.1, TP3.1 (1_1), U3.23 (DVDD), U3.45 (VREG_VOUT), U3.50 (DVDD)
+3V3: C3.1, C4.1, C5.1, C6.1, C7.1, C8.1, C9.1, C10.1, C12.1, C13.1, C15.1, C19.2, C20.2, J4.1, J5.4, R5.1, TP2.1 (1_1), U1.5 (VOUT), U2.8 (VCC), U3.1 (IOVDD), U3.10 (IOVDD), U3.22 (IOVDD), U3.33 (IOVDD), U3.42 (IOVDD), U3.43 (ADC_AVDD), U3.44 (VREG_IN), U3.48 (USB_VDD), U3.49 (IOVDD), U4.8 (VCC)
/5V_LOCAL: C11.1, D1.1 (-), D2.1 (-), TP1.1 (1_1), U1.1 (VIN), U1.3 (EN)
/ADDR_IN: J3.7, U3.14 (GPIO11)
/ADDR_OUT: J2.7, U3.13 (GPIO10)
/BL_PWM: R12.1, U3.32 (GPIO21)
/CS: J5.8, U3.31 (GPIO20)
/D/C: J5.7, U3.28 (GPIO17)
/GPIO12_TX: U3.15 (GPIO12), U4.4 (DI)
/GPIO13_RX: U3.16 (GPIO13), U4.1 (RO)
/GPIO14_RE: R10.1, U3.17 (GPIO14), U4.2 (~RE)
/GPIO15_DE: R9.1, U3.18 (GPIO15), U4.3 (DE)
/LEDA: J5.3, R11.2
/LEDK: J5.2, Q1.3 (C)
/QSPI_SCLK: U2.6 (CLK), U3.52 (QSPI_SCLK)
/QSPI_SD0: U2.5 (DI/IO_{0}), U3.53 (QSPI_SD0)
/QSPI_SD1: U2.2 (DO/IO_{1}), U3.55 (QSPI_SD1)
/QSPI_SD2: U2.3 (~WP/IO_{2}), U3.54 (QSPI_SD2)
/QSPI_SD3: U2.7 (~HOLD/~RESET/IO_{3}), U3.51 (QSPI_SD3)
/QSPI_SS: R5.2, R6.2, U2.1 (~CS), U3.56 (QSPI_~SS)
/RESET: J5.11, U3.27 (GPIO16)
/RS485_A: J2.5, J3.5, R8.1, TP4.1 (1_1), U4.6 (A)
/RS485_B: J2.6, J3.6, JP1.2 (B), TP5.1 (1_1), U4.7 (B)
/RUN: J4.3, U3.26 (RUN)
/SPARE_IN: J3.8, U3.12 (GPIO9)
/SPARE_OUT: J2.8, U3.11 (GPIO8)
/SPI0_SCK (SCL): J5.9, U3.29 (GPIO18)
/SPI0_TX (MOSI): J5.10, U3.30 (GPIO19)
/SWCLK: J4.4, U3.24 (SWCLK)
/SWDIO: J4.2, U3.25 (SWD)
/USB-C_CC1: J1.A5 (CC1), R1.1
/USB-C_CC2: J1.B5 (CC2), R2.1
/USB_D+: J1.A7 (D-), J1.B7 (D-), R3.2
/USB_D-: J1.A6 (D+), J1.B6 (D+), R4.2
/USB_MCU_D+: R3.1, U3.47 (USB_DP)
/USB_MCU_D-: R4.1, U3.46 (USB_DM)
/VBUS_USB-C: D2.2 (+), J1.A4 (VBUS), J1.A9 (VBUS), J1.B4 (VBUS), J1.B9 (VBUS)
/XIN: C17.2, U3.20 (XIN), Y1.1
/XOUT: R7.2, U3.21 (XOUT)
/~USB_BOOT: R6.1, SW1.2 (B)
GND: C1.2, C2.2, C3.2, C4.2, C5.2, C6.2, C7.2, C8.2, C9.2, C10.2, C11.2, C12.2, C13.2, C14.2, C15.2, C16.1, C17.1, C18.1, C19.1, C20.1, J1.A1 (GND), J1.A12 (GND), J1.B1 (GND), J1.B12 (GND), J1.SH (SHIELD), J2.1, J2.4, J2.9, J2.10, J3.1, J3.4, J3.9, J3.10, J4.5, J4.6, J5.1, J5.5, J5.6, J5.12, J5.13, J5.14, Q1.2 (E), R1.2, R2.2, R9.2, R10.2, R13.2, SW1.4 (D), U1.2 (GND), U2.4 (GND), U3.19 (TESTEN), U3.57 (GND), U4.5 (GND), Y1.2 (GND), Y1.4 (GND)
unnamed: C18.2, R7.1, Y1.3
unnamed: JP1.1 (A), R8.2
unnamed: Q1.1 (B), R12.2, R13.1
VBUS +5V: C16.2, D1.2 (+), J2.2, J2.3, J3.2, J3.3, R11.1

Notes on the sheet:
Power supply
Decoupling capacitors for RP2040
Crystal oscillator
Make sure C8 is close to pin 45 of RP2040
SWD Debug
Daisy chain connector
SPI display
Place crystal as close as possible to RP2040
Make sure C10 is close to pin 44 of RP2040
RS485
Place C18 as close as possible to pin 8. Place C19 on the same 3V3 feed immediately upstream of C18, within 5 mm.
Keep QSPI traces as short as possible
Make sure R3 and R4 are close to RP2040
RP2040
Use at least two vias for VCC and ground connections of decoupling capacitors.
Flash storage

Board: 4 copper layers, 53 parts (0 on the bottom side), 44 nets, no tracks yet.

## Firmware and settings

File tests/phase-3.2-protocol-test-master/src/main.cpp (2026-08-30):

#include <Arduino.h>
#include <hardware/clocks.h>
#include "pin_definitions.h"
#include "protocol.h"

/*
 * Phase 3.2 -- protocol master.
 *
 * Broadcasts the real thing, not a reduced stand-in: a full 288-byte
 * GlobalClockUpdate covering all 72 nodes, 60 times per second, exactly as the
 * finished clock would. A smaller test packet would sail over the bus and prove
 * nothing about whether the design actually fits in the RS485 budget.
 *
 * Budget check, against the ~100 kB/s ceiling measured in phase 2.1:
 *   288 B payload -> 295 B on the wire after COBS
 *   295 B x 60 Hz = 17.7 kB/s   (about 18% of the bus)
 *
 * All four command types are exercised. Which ones are on the bus right now is
 * controlled by single-key commands over USB serial (press '?' for the list),
 * but the default mode cycles through everything on its own -- so the master
 * still tests the whole protocol when it is running headless off a USB brick
 * with no terminal attached.
 */

/*
 * ---------------------------------------------------------
 * WHAT IS ON THE BUS
 * ---------------------------------------------------------
 * A "phase" is the traffic pattern currently being transmitted. A "mode" is
 * what the operator asked for: the two pinned modes hold one phase forever,
 * MODE_ALL rotates between them on a timer.
 */
enum Phase : uint8_t {
  PHASE_CLOCK,    // CLOCK_INIT once, then CLOCK_UPDATE at the current rate
  PHASE_WIDGET,   // WIDGET_INIT once, then WIDGET_UPDATE, node-targeted
  PHASE_IDLE      // silence -- the slaves should drop to 0 fps and freeze
};

enum Mode : uint8_t {
  MODE_ALL,       // rotate CLOCK <-> WIDGET, so every command type gets sent
  MODE_CLOCK,     // pinned to PHASE_CLOCK: the clean smoothness run
  MODE_WIDGET,    // pinned to PHASE_WIDGET
  MODE_STOP       // pinned to PHASE_IDLE
};

static Mode  mode  = MODE_ALL;
static Phase phase = PHASE_CLOCK;

// How long MODE_ALL spends in each phase before rotating. The clock phase is
// the longer one: it is the one whose frame rate is actually worth measuring.
const unsigned long CLOCK_PHASE_MS  = 8000;
const unsigned long WIDGET_PHASE_MS = 4000;

// The CLOCK_UPDATE rate is steppable at runtime with '+' / '-'. 60 Hz is the
// design target; 90 and 120 exist to find out what gives out first, the bus or
// the node's render loop.
const uint16_t RATE_TABLE[] = { 30, 60, 90, 120 };
const uint8_t  RATE_COUNT   = sizeof(RATE_TABLE) / sizeof(RATE_TABLE[0]);
static uint8_t rateIndex    = 1;   // -> 60 Hz

// Microseconds, not milliseconds. A 16 ms millis() tick is really 62.5 Hz and
// cannot be stepped finely enough to reach a clean 90 or 120.
static uint32_t sendIntervalUs = 1000000UL / 60;

const unsigned long INIT_INTERVAL_MS        = 5000;  // re-broadcast config during the clock phase
const unsigned long WIDGET_INTERVAL_ALL_MS  = 2000;  // widget traffic mixed into the clock phase
const unsigned long WIDGET_INTERVAL_MS      = 500;   // 2 Hz while the widget phase owns the bus
const unsigned long REPORT_INTERVAL_MS      = 1000;  // throughput report over USB

// The node IDs the two bench slaves are flashed with -- see MY_NODE_ID in the
// slave's platformio.ini. Only WIDGET_UPDATE is node-targeted; everything else
// is a broadcast, so this list exists purely so widget frames alternate between
// the two boards that are actually on the bench.
const uint8_t SLAVE_NODES[] = { 0, 36 };
const uint8_t SLAVE_COUNT   = sizeof(SLAVE_NODES) / sizeof(SLAVE_NODES[0]);

// Hand rotation speeds, matching the phase-1.1 display test (20 and 100 deg/s).
//
// The angles are accumulated in MILLIdegrees, not whole degrees. At 60 Hz the
// slower hand only moves ~0.33 deg per packet, so a whole-degree accumulator
// would truncate every step to 0 and the hand would never move. Millidegrees
// give the accumulator enough headroom to keep integer math exact, and the
// value is divided down to tenths of a degree only when the packet is filled.
//
// Handy coincidence: millidegrees-per-millisecond is the same number as
// degrees-per-second, so these constants read as their real-world speed.
const uint32_t HAND1_MDEG_PER_MS = 20;    // deg/s
const uint32_t HAND2_MDEG_PER_MS = 100;   // deg/s
const uint32_t FULL_TURN_MDEG = 360000;   // one revolution

// Each node is given a fixed slice of a revolution as its starting offset, so
// no two displays sit at the same angle. That is what makes it obvious on the
// bench that every slave is reading ITS OWN slot of the broadcast rather than
// slot 0 -- if the addressing were broken, all displays would move in unison.
const uint32_t NODE_PHASE_MDEG = FULL_TURN_MDEG / TOTAL_MATRIX_NODES;

// Kept off the stack: together these are ~600 bytes, and buildFrame() needs
// another 292 for its own assembly buffer.
static GlobalClockUpdate txUpdate;
static uint8_t txBuf[MAX_ENCODED_FRAME];

static uint8_t sequenceCounter = 0;

// Bytes actually put on the wire since the last report, for the budget check.
static uint32_t bytesThisSecond = 0;
static uint32_t framesThisSecond = 0;

// Sends one frame and accounts for it. Returns false if the frame could not be
// built, which would mean a programming error rather than a bus problem.
static bool sendFrame(CommandType cmd, uint8_t targetNode,
                      const void* payload, size_t payloadLen) {
  size_t n = buildFrame(cmd, targetNode, sequenceCounter++, payload, payloadLen,
                        txBuf, sizeof(txBuf));
  if (n == 0) {
    Serial.println("[ERROR] buildFrame failed -- payload too large for the buffer?");
    return false;
  }

  Serial1.write(txBuf, n);
  Serial1.flush();          // let the UART drain before the next frame is queued

  bytesThisSecond += n;
  framesThisSecond++;
  return true;
}

/*
 * ---------------------------------------------------------
 * INIT PAYLOADS
 * ---------------------------------------------------------
 * Both init commands cycle through a small table of presets. That is what makes
 * an init frame VISIBLE rather than merely logged: press 'i' and the hands
 * change colour on the spot. The periodic re-broadcast does not advance the
 * table, so a slave that reboots mid-test picks the config back up without the
 * face changing under an operator who did not ask for it.
 */
static const ClockInitData CLOCK_PRESETS[] = {
  // hand1  hand2   bg      len1 len2 thk1 thk2
  { 0xF800, 0xFFFF, 0x0000, 60,  90,  8,   4 },   // red / white
  { 0x07E0, 0xFFE0, 0x0000, 75,  95,  6,   3 },   // green / yellow, longer
  { 0x001F, 0xF81F, 0x0000, 50,  80, 10,   5 }    // blue / magenta, stubbier
};
const uint8_t CLOCK_PRESET_COUNT = sizeof(CLOCK_PRESETS) / sizeof(CLOCK_PRESETS[0]);
static uint8_t clockPreset = 0;

static const uint16_t WIDGET_BG_PRESETS[] = { 0x001F, 0x03E0, 0x7800 };  // navy, dark green, maroon
const uint8_t WIDGET_PRESET_COUNT = sizeof(WIDGET_BG_PRESETS) / sizeof(WIDGET_BG_PRESETS[0]);
static uint8_t widgetPreset = 0;

// Pushes the clock-face configuration every node needs before it can render.
static void broadcastClockInit() {
  sendFrame(CMD_CLOCK_INIT, GLOBAL_BROADCAST_ID,
            &CLOCK_PRESETS[clockPreset], sizeof(ClockInitData));
}

static void broadcastWidgetInit() {
  WidgetInitData init;
  init.widgetType  = 1;
  init.bgColor     = WIDGET_BG_PRESETS[widgetPreset];
  init.fieldCount  = 1;
  init.reserved[0] = 0;
  init.reserved[1] = 0;

  sendFrame(CMD_WIDGET_INIT, GLOBAL_BROADCAST_ID, &init, sizeof(init));
}

// Widget updates are node-targeted and carry only the bytes they actually use,
// so this frame is ~14 bytes on the wire rather than the full 33 the struct
// could hold. The text names the node it was addressed to, so a targeting bug
// shows up on the glass: both displays would read the same label.
static uint32_t widgetCounter = 0;

static void sendWidgetUpdate(uint8_t targetNode) {
  WidgetUpdateData widget;
  widget.fieldId = 1;

  char text[MAX_WIDGET_DATA];
  int len = snprintf(text, sizeof(text), "N%u #%lu",
                     (unsigned)targetNode, (unsigned long)widgetCounter);
  if (len < 0) return;
  if (len > int(sizeof(text)) - 1) len = int(sizeof(text)) - 1;   // snprintf truncated

  memcpy(widget.data, text, (size_t)len);
  sendFrame(CMD_WIDGET_UPDATE, targetNode, &widget, 1 + (size_t)len);
}

/*
 * ---------------------------------------------------------
 * PHASE / MODE CONTROL
 * ---------------------------------------------------------
 */
static const char* phaseName(Phase p) {
  switch (p) {
    case PHASE_CLOCK:  return "CLOCK";
    case PHASE_WIDGET: return "WIDGET";
    case PHASE_IDLE:   return "IDLE";
  }
  return "?";
}

static unsigned long phaseStartedAt = 0;

// When the next CLOCK_UPDATE is due, and the leftover microseconds that have
// not yet added up to a whole millisecond of hand movement. Both live out here
// rather than inside loop() so entering the clock phase can reset them: the
// widget phase does not send clock updates, so without a reset the first packet
// after it would report the entire widget phase as elapsed time and jump the
// hands the better part of a revolution.
static uint32_t lastSendUs = 0;
static uint32_t usCarry    = 0;

// Entering a phase is what sends its init frame -- the slaves switch what they
// render off the last init they saw, so this is also the display mode switch.
static void enterPhase(Phase p) {
  phase = p;
  phaseStartedAt = millis();

  switch (p) {
    case PHASE_CLOCK:
      lastSendUs = micros();
      usCarry    = 0;
      broadcastClockInit();
      break;
    case PHASE_WIDGET: broadcastWidgetInit(); break;
    case PHASE_IDLE:   break;                        // say nothing, send nothing
  }

  Serial.print("[phase] ");
  Serial.println(phaseName(p));
}

static void printHelp() {
  Serial.println();
  Serial.println("  a   ALL     rotate CLOCK <-> WIDGET + widget frames mixed in: all 4 types");
  Serial.println("  c   CLOCK   CLOCK_INIT once, then CLOCK_UPDATE only (clean fps run)");
  Serial.println("  w   WIDGET  WIDGET_INIT once, then WIDGET_UPDATE, alternating nodes");
  Serial.println("  s   STOP    bus goes silent, slaves should fall to 0 fps");
  Serial.println("  i   send one CLOCK_INIT now  (next preset: hands change colour)");
  Serial.println("  I   send one WIDGET_INIT now (next background colour)");
  Serial.println("  u   send one WIDGET_UPDATE now");
  Serial.println("  +/- step the CLOCK_UPDATE rate: 30 / 60 / 90 / 120 Hz");
  Serial.println("  ?   this help");
  Serial.println();
}

static void setMode(Mode m) {
  mode = m;
  switch (m) {
    case MODE_ALL:    Serial.println("[mode] ALL");    enterPhase(PHASE_CLOCK);  break;
    case MODE_CLOCK:  Serial.println("[mode] CLOCK");  enterPhase(PHASE_CLOCK);  break;
    case MODE_WIDGET: Serial.println("[mode] WIDGET"); enterPhase(PHASE_WIDGET); break;
    case MODE_STOP:   Serial.println("[mode] STOP");   enterPhase(PHASE_IDLE);   break;
  }
}

static void stepRate(int8_t dir) {
  int8_t next = int8_t(rateIndex) + dir;
  if (next < 0 || next >= int8_t(RATE_COUNT)) return;   // clamp at the ends

  rateIndex = uint8_t(next);
  sendIntervalUs = 1000000UL / RATE_TABLE[rateIndex];

  Serial.print("[rate] CLOCK_UPDATE at ");
  Serial.print(RATE_TABLE[rateIndex]);
  Serial.println(" Hz");
}

static void handleCommand(char c) {
  switch (c) {
    case 'a': setMode(MODE_ALL);    break;
    case 'c': setMode(MODE_CLOCK);  break;
    case 'w': setMode(MODE_WIDGET); break;
    case 's': setMode(MODE_STOP);   break;

    case 'i':
      clockPreset = (clockPreset + 1) % CLOCK_PRESET_COUNT;
      broadcastClockInit();
      Serial.print("[send] CLOCK_INIT preset ");
      Serial.println(clockPreset);
      break;

    case 'I':
      widgetPreset = (widgetPreset + 1) % WIDGET_PRESET_COUNT;
      broadcastWidgetInit();
      Serial.print("[send] WIDGET_INIT preset ");
      Serial.println(widgetPreset);
      break;

    case 'u':
      sendWidgetUpdate(SLAVE_NODES[widgetCounter % SLAVE_COUNT]);
      widgetCounter++;
      Serial.println("[send] WIDGET_UPDATE");
      break;

    case '+': stepRate(+1); break;
    case '-': stepRate(-1); break;

    case '?': printHelp(); break;

    case '\r':
    case '\n':
    case ' ':
      break;                                    // line noise from the terminal

    default:
      Serial.print("[?] unknown command '");
      Serial.print(c);
      Serial.println("' -- press ? for the list");
      break;
  }
}

void setup() {
  // bind the peripheral clock to the system clock (133 MHz)
  clock_configure(clk_peri,
                  0,
                  CLOCKS_CLK_PERI_CTRL_AUXSRC_VALUE_CLK_SYS,
                  clock_get_hz(clk_sys),
                  clock_get_hz(clk_sys));

  // 1. Start USB Serial for communication with PC
  Serial.begin(115200);
  while (!Serial && millis() < 2000); // Wait up to 2 seconds for USB serial to connect
  Serial.println("RS485 Master Initializing...");

  // 2. Configure the RS485 module for transmit mode
  pinMode(RS485_CTRL_PIN, OUTPUT);
  digitalWrite(RS485_CTRL_PIN, HIGH);

  // 3. Setup Hardware Serial (UART0) pins and baud rate
  Serial1.setTX(RS485_TX_PIN);
  Serial1.setRX(RS485_RX_PIN);
  Serial1.begin(RS485_BAUD_RATE);

  Serial.print("Protocol v");
  Serial.print(PROTOCOL_VERSION);
  Serial.print(" | CLOCK_UPDATE payload ");
  Serial.print((unsigned)sizeof(GlobalClockUpdate));
  Serial.print(" B, max frame ");
  Serial.print((unsigned)MAX_ENCODED_FRAME);
  Serial.println(" B");

  printHelp();
  setMode(MODE_ALL);        // sends the first CLOCK_INIT
  Serial.println("Master ready. Broadcasting packets...");
}

void loop() {
  // Initialized on the first call to loop(), i.e. after setup() has already
  // burned up to 2 seconds waiting for USB serial -- starting these from 0
  // would make every one of them fire immediately on the first pass.
  static unsigned long lastInitTime   = millis();
  static unsigned long lastWidgetTime = millis();
  static unsigned long lastReportTime = millis();

  // Current hand positions for node 0, in millidegrees (see the constants
  // above). Every other node is this plus its own phase offset.
  static uint32_t angle1Milli = 0, angle2Milli = 0;

  unsigned long now = millis();

  // ---- operator commands over USB ----
  while (Serial.available() > 0) {
    handleCommand((char)Serial.read());
  }

  // ---- MODE_ALL: rotate between the two phases on a timer ----
  if (mode == MODE_ALL) {
    unsigned long limit = (phase == PHASE_CLOCK) ? CLOCK_PHASE_MS : WIDGET_PHASE_MS;
    if (now - phaseStartedAt >= limit) {
      enterPhase(phase == PHASE_CLOCK ? PHASE_WIDGET : PHASE_CLOCK);
    }
  }

  // ---- the full 72-node clock broadcast, at the selected rate ----
  // micros() wraps every ~71 minutes; the unsigned subtraction below is
  // correct across that wrap, which a "deadline" comparison would not be.
  uint32_t nowUs = micros();
  if (phase == PHASE_CLOCK && (nowUs - lastSendUs) >= sendIntervalUs) {
    // How much time actually passed since the last packet. Using the real
    // elapsed time, rather than assuming exactly one interval, keeps the hands
    // turning at the right speed even if a loop runs late.
    uint32_t elapsedUs = nowUs - lastSendUs;
    lastSendUs = nowUs;

    // The angle math works in millidegrees per MILLIsecond, so carrying the
    // sub-millisecond remainder is what keeps the hands at exactly the right
    // speed instead of losing a fraction of a step to truncation every packet.
    usCarry += elapsedUs;
    uint32_t elapsedMs = usCarry / 1000;
    usCarry -= elapsedMs * 1000;

    // Advance both hands, wrapping at a full revolution.
    angle1Milli = (angle1Milli + HAND1_MDEG_PER_MS * elapsedMs) % FULL_TURN_MDEG;
    angle2Milli = (angle2Milli + HAND2_MDEG_PER_MS * elapsedMs) % FULL_TURN_MDEG;

    // Fill all 72 slots. Tenths of a degree, 0..3599, is the resolution the
    // wire carries and exactly what the slave hands to ClockFace::prepareFrame(),
    // so no conversion happens on the receiving end. Whole degrees weren't
    // enough: at these speeds a hand can move less than 1 degree between
    // packets, which made the motion step unevenly instead of gliding.
    for (uint8_t node = 0; node < TOTAL_MATRIX_NODES; node++) {
      uint32_t offset = uint32_t(node) * NODE_PHASE_MDEG;
      txUpdate.nodes[node].angle1DeciDeg =
          uint16_t(((angle1Milli + offset) % FULL_TURN_MDEG) / 100);
      txUpdate.nodes[node].angle2DeciDeg =
          uint16_t(((angle2Milli + offset) % FULL_TURN_MDEG) / 100);
    }

    sendFrame(CMD_CLOCK_UPDATE, GLOBAL_BROADCAST_ID, &txUpdate, sizeof(txUpdate));
  }

  // ---- every 5 s during the clock phase: re-broadcast the configuration ----
  // Deliberately does NOT advance the preset, so this is a no-op for a slave
  // that already has the config -- it only matters to one that just rebooted.
  if (now - lastInitTime >= INIT_INTERVAL_MS) {
    lastInitTime = now;
    if (phase == PHASE_CLOCK) broadcastClockInit();
  }

  // ---- the node-targeted widget path ----
  // During the clock phase these still go out, just rarely: the slaves count
  // and validate them without drawing, which keeps the parser's variable-length
  // path under test even while the clock is the thing on screen.
  bool widgetsWanted = (phase == PHASE_WIDGET) ||
                       (phase == PHASE_CLOCK && mode == MODE_ALL);
  unsigned long widgetInterval =
      (phase == PHASE_WIDGET) ? WIDGET_INTERVAL_MS : WIDGET_INTERVAL_ALL_MS;
  if (widgetsWanted && now - lastWidgetTime >= widgetInterval) {
    lastWidgetTime = now;
    sendWidgetUpdate(SLAVE_NODES[widgetCounter % SLAVE_COUNT]);
    widgetCounter++;
  }

  // ---- once a second: report what the bus is actually carrying ----
  if (now - lastReportTime >= REPORT_INTERVAL_MS) {
    unsigned long window = now - lastReportTime;
    lastReportTime = now;

    Serial.print("TX ");
    Serial.print(framesThisSecond * 1000.0f / window, 1);
    Serial.print(" frames/s | ");
    Serial.print(bytesThisSecond * 1000.0f / window / 1000.0f, 1);
    Serial.print(" kB/s of ~100 kB/s | ");
    Serial.print(phaseName(phase));
    Serial.print(" @ ");
    Serial.print(RATE_TABLE[rateIndex]);
    Serial.print(" Hz | seq ");
    Serial.println(sequenceCounter);

    bytesThisSecond = 0;
    framesThisSecond = 0;
  }
}

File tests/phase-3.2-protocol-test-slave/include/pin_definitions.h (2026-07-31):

#pragma once

// ---------------------------------------------------------
// RS485 Hardware Configuration
// ---------------------------------------------------------

// UART0 Pins
const int RS485_TX_PIN = 12;   // Connects to DI (Data In) on the RS485 module
const int RS485_RX_PIN = 13;   // Connects to RO (Receive Out) on the RS485 module

// Transceiver Direction Control Pin
const int RS485_CTRL_PIN = 15; // Connects to BOTH DE and RE on the RS485 module
                              // HIGH = Transmit Mode
                              // LOW  = Receive Mode

// Serial Communication Speed
const long RS485_BAUD_RATE = 1000000;


// Display Connection over SPI
const int PIN_SCLK = 18; // SCL
const int PIN_MOSI = 19;  // SDA
const int PIN_MISO = -1;  // not wired, GC9A01 used write-only
const int PIN_CS = 20;
const int PIN_DC = 17;
const int PIN_RST = 16;
const int PIN_BL = -1;  // backlight tied to a fixed rail on this breakout

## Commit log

2026-08-06 Refactor comments in protocol.h for clarity
    Updated comments for clarity and accuracy regarding COBS encoding, struct packing, and frame processing.
2026-09-11 Add new documentation and resources for Node PCB project
    - Added BOM spreadsheet for Node PCB design.
    - Included datasheet for GC9A01A display driver.
    - Added RP2040 design example schematic.
    - Included PCB block diagram image.
    - Added minimal design example image for RP2040.
    [node-pcb.kicad_pcb, node-pcb.kicad_sch, node-pcb_BOM.xlsx]
2026-09-13 Add lock files and new images for documentation
    - Created lock files for KiCad PCB, Pro, and schematic with user and hostname information.
    - Added new images for minimal example power, schematic power, and wiring diagram to the documentation.
    [node-pcb.kicad_sch]
2026-09-13 Add new images for documentation and update existing schematic
    - Added minimal example flash image to the documentation.
    - Added schematic flash image to the documentation.
    - Updated existing schematic power image.
2026-09-15 Remove lock files and add new datasheets and images for display components and RS485 schematic
    [node-pcb.kicad_sch]
2026-09-17 Update pcb schematic
    [node-pcb.kicad_sch]
2026-09-19 Add schematic diagrams and images for Node PCB
    - Added schematic.pdf for overall PCB design.
    - Included schematic-connector.png for connector details.
    - Added schematic-debug.png for debugging interface.
    - Updated schematic-rs485.png with new changes.
    - Introduced schematic-spi.png for SPI interface representation.
    [node-pcb.kicad_sch]
2026-09-23 Add new datasheets and images; update test documentation
    - Added Schottky diode datasheet (B5817W-589W) to the documentation.
    - Included a simplified PSU circuit image for reference.
    - Added an image illustrating the voltage drop across a Schottky diode.
    - Updated the existing wiring diagram image.
    - Enhanced the test README with a new section on PCB prototype design, outlining objectives for testing resistance, current, and voltage.
    [node-pcb.kicad_sch, node-pcb_BOM.csv]
2026-09-23 Update schematic and documentation
    [node-pcb.kicad_sch, node-pcb_BOM.csv, node-pcb_BOM.xlsx]
2026-10-02 Add BOM CSV and schematic PDF for node-pcb design
    - Created a new BOM CSV file detailing components used in the node-pcb project, including specifications such as reference, description, quantity, part numbers, and links to datasheets.
    - Added a new schematic PDF file for the node-pcb design to provide a visual representation of the circuit layout.
    [node-pcb.kicad_pcb, node-pcb.kicad_sch, node-pcb_BOM.csv]
2026-10-04 Update schematic PDF with latest design revisions
2026-10-05 Refactor PCB and schematic files for improved clarity and functionality
    - Updated PCB netclass assignments from "Power" to "Default" for better consistency.
    - Changed PCB color settings to transparent for the "Power" netclass.
    - Adjusted clearance value for the "QSPI" netclass from 0.3 to 0.2.
    - Removed redundant no_connect entries and added a new no_connect entry in the schematic.
    - Added new wire connections in the schematic for better signal integrity.
    - Renamed label "ADDR_IN" to "SPARE_IN" and adjusted its position, while creating a new "ADDR_IN" label at a different location.
    - Cleaned up used designators in the PCB file for better organization.
2026-10-11 Refactor BOM CSV for component grouping and update part references
    - Consolidated multiple entries for ceramic capacitors into grouped lines for better readability and management.
    - Updated the header of the BOM CSV to reflect changes in part categorization.
    - Added new entries for components with extended and basic classifications.
    - Introduced a lock file for KiCad project to track user session.
    - Updated schematic PDF to reflect recent changes in the design.
2026-10-11 Add production files and update PCB layout for node-pcb
    - Created BOM-node-pcb.csv to list components with details for production.
    - Added CPL-node-pcb.csv for component placement information.
    - Introduced project.db for project metadata.
    - Updated node-pcb.kicad_pcb with new segments and vias for improved routing.
    - Modified node-pcb.kicad_pro to adjust net colors and track design settings.
    - Removed outdated node-pcb_BOM.csv and temporary lock file.
2026-10-14 - Updated PCB design - added link to CAD files
2026-10-21 Updated pcb production files
2026-11-05 First PCB bring up tests completed successfully
2026-11-07 Add SWD debugging support for prototype PCB; include PlatformIO configuration and example code
2026-11-08 Add backlight PWM control and update documentation for phase 5.1 tests
    - Implemented backlight PWM control for the prototype PCB using GPIO21.
    - Added new test files and updated existing ones to include backlight functionality.
    - Enhanced README files with detailed instructions for backlight PWM testing.
    - Updated PlatformIO configuration for new test environment.
2026-11-11 Enhance RS485 protocol support for node PCB v1.0; add DE pin configuration and backlight control
2026-11-14 Add power supply documentation and implement power chain tests
